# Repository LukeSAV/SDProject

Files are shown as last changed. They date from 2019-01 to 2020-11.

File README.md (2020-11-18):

# **SDProject**

Repo for senior design code

Link to project video: https://www.youtube.com/watch?v=O6JMgqfRybo&t=1s

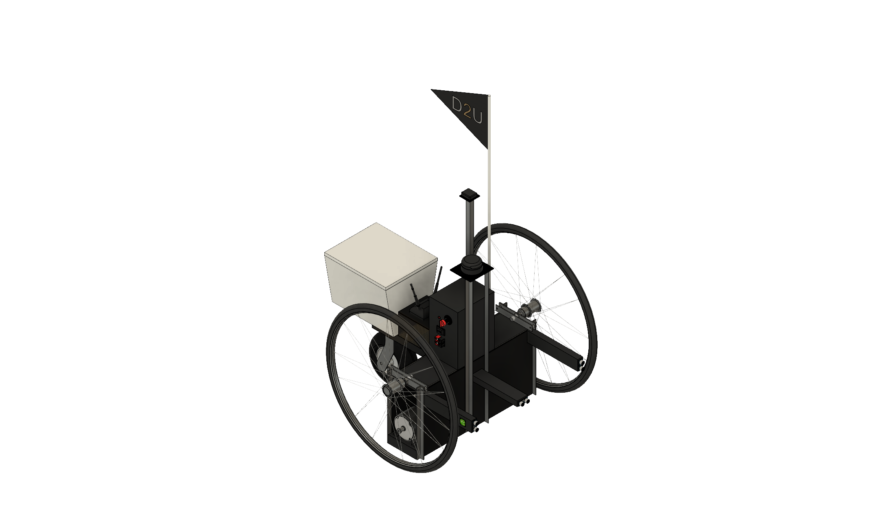
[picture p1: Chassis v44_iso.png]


## <u>Matlab</u>

Contains matlab test harness and associated files for the Extended Kalman Filter - This has since been converted to ekf_node in the ROS workspace.

## <u>SDMicro</u>

Contains all microcontroller related code for the project.

## <u>boards</u>

Contains files related to PCB design and schematics.

## <u>iOS</u>

This contains all project files related to XCode and iOS. 

##### /D2U

DeliveryInformation.swift - Singleton class used to hold relevant information to the delivery in progress.

DeliverySettingsController.swift - ViewController for the settings page. Formats and periodically updates the information on the page from FireBase.

MapMainController.swift - ViewController for the main map page. Handles map centering on desired user location and updates respective UI elements.

Waypoint.swift - Inherits MKPointAnnotation to apply color to dropped pins to distinguish between types.

## <u>ros_ws</u>

This is the ROS workspace for the project. Any packages/nodes made in ROS should be located here.

#### ROS Packages:

##### fb

This package contains the fb_node that handles interfacing to firebase. 

Nodes:

- fb_node: 
  - Publishes - /delivery_requested_status (Type: Bool)
  - Subscribes - /rtk_gpgga (Type: String)

##### rtk

This package contains the rtk_gps_node that runs code to support RTK corrections for the NS-HP-GL GPS/GNSS device. 

Nodes:

- rtk_gps_node
  - Publishes - /rtk_gpgga (Type: NavSatFix), /rtk_gpvtg (Type: HeadingSpeed)
  - Subscribes - None

##### rtk_controller

This package contains the rtk_controller node that performs path point generation to send to the microcontroller. A* algorithm, path point projection, and much more.

Nodes:

- rtk_controller_node
  - Publishes - /robot_cmd (Type: String), /next_waypoint (Type: NavSatFix), /goal_pt (Type: NavSatFix), /goal_math_pt (Type: NavSatFix)
  - Subscribes - /ekf/filtered (Type: NavSatFix), /ekf/imu/data (Type: Imu), /rtk_gpvtg (Type: String), /perception/map (Type: Image), /pitch (Type: Float32) 

##### joystick_drivers

This package contains the joy_node that interfaces the PS4 controller to ROS.

Nodes:

- joy_node: 
  - Publishes - /joy (Type: Joy)
  - Subscribes - None 

##### serial

This package contains the serial_node that handles all communication with the microcontroller.

Nodes:

- serial_node:
  - Publishes - /encoder (Type: String), /goal_string (Type: String)
  - Subscribes - /joy (Type: Joy), /delivery_requested_status (Type: Bool), /robot_cmd (Type: String)

##### perception

This package contains the lidar_node that handles creation of an obstacle map that the path planning algorithm may be run on.

Nodes:
- lidar_node:
  - Publishes - /perception/map (Type: Image)
  - Subscribes - /scan_img (Type: Image)
  
##### ekf

This package contains the ekf_node that runs the Extended Kalman Filter to fuse the robot sensor information.

Nodes:
- ekf_node:
  - Publishes - /ekf/filtered (Type: NavSatFix), /ekf/imu/data (Type: NavSatFix), /pitch (Type: Float32)
  - Subscribes - /imu/data (Type: Imu), /rtk_gpgga (Type: NavSatFix), /encoder (Type: String)

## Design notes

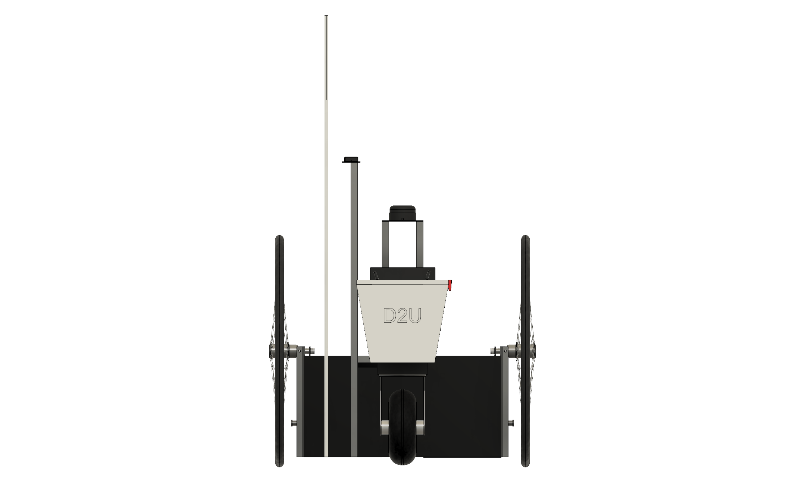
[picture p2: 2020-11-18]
Chassis v44_rear.png

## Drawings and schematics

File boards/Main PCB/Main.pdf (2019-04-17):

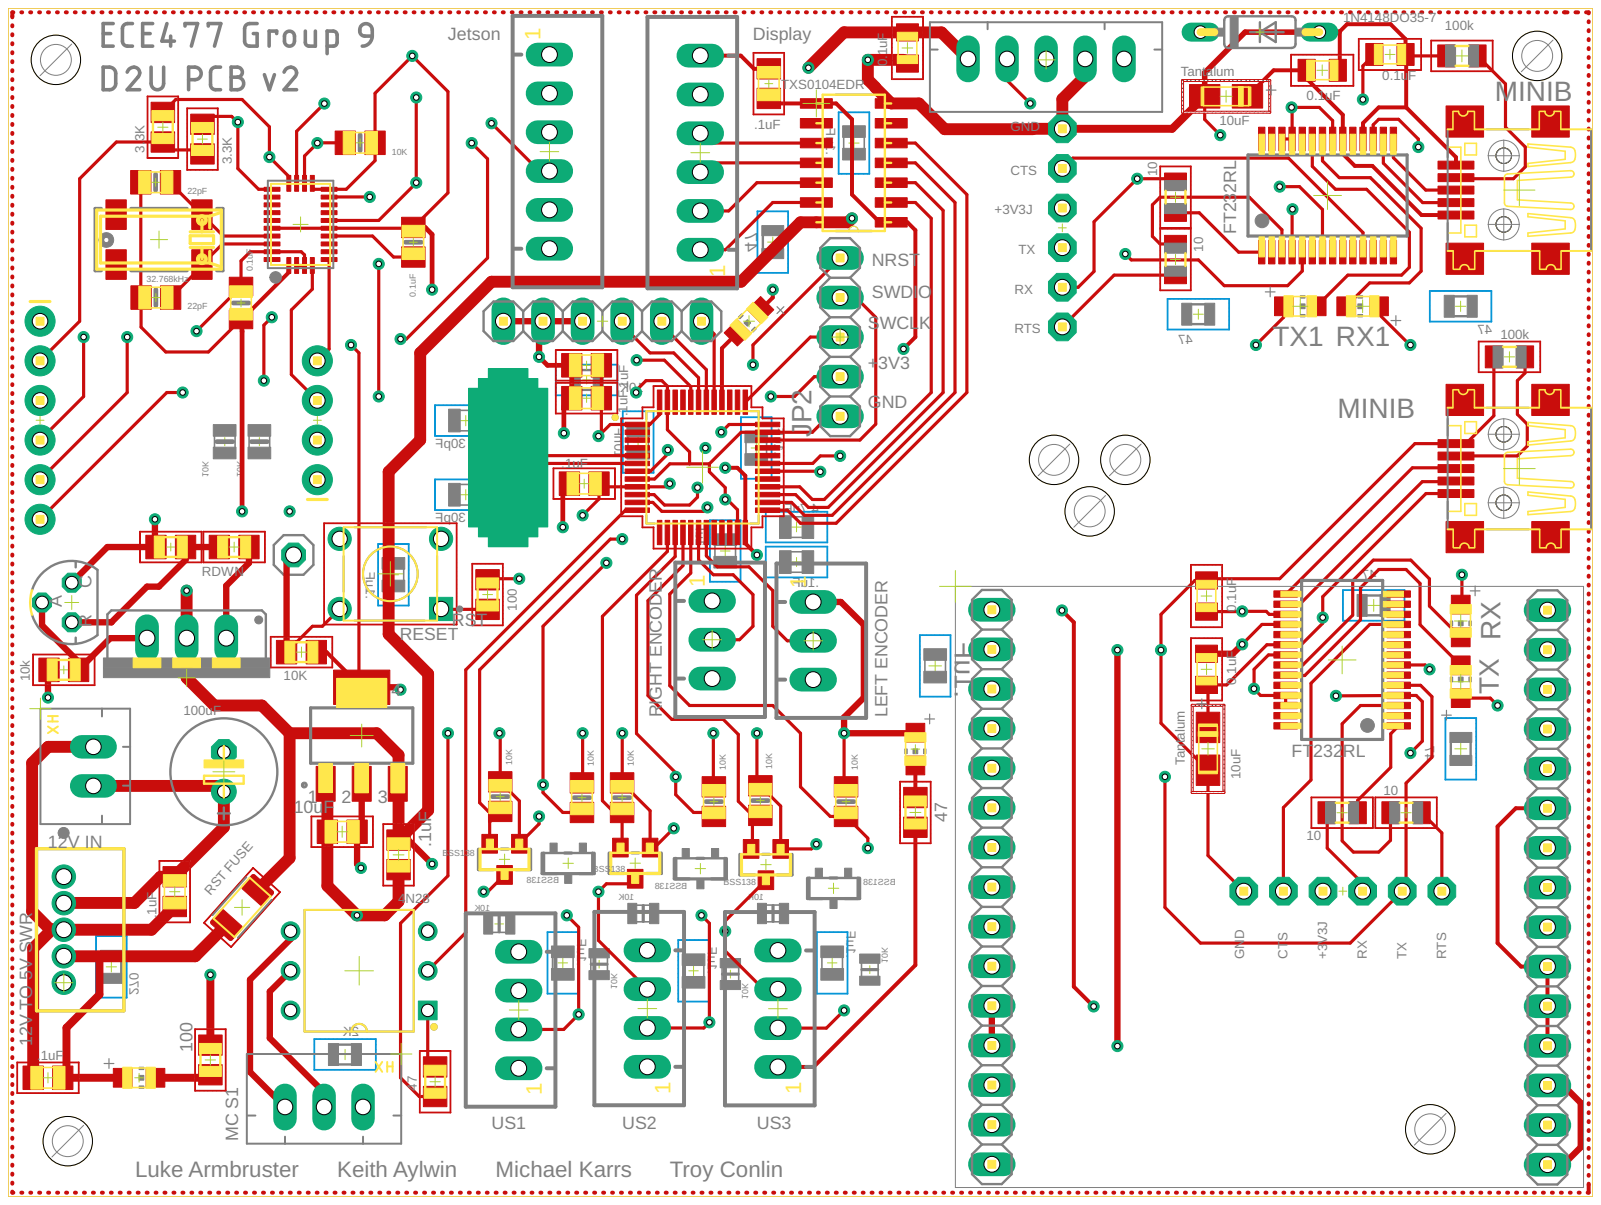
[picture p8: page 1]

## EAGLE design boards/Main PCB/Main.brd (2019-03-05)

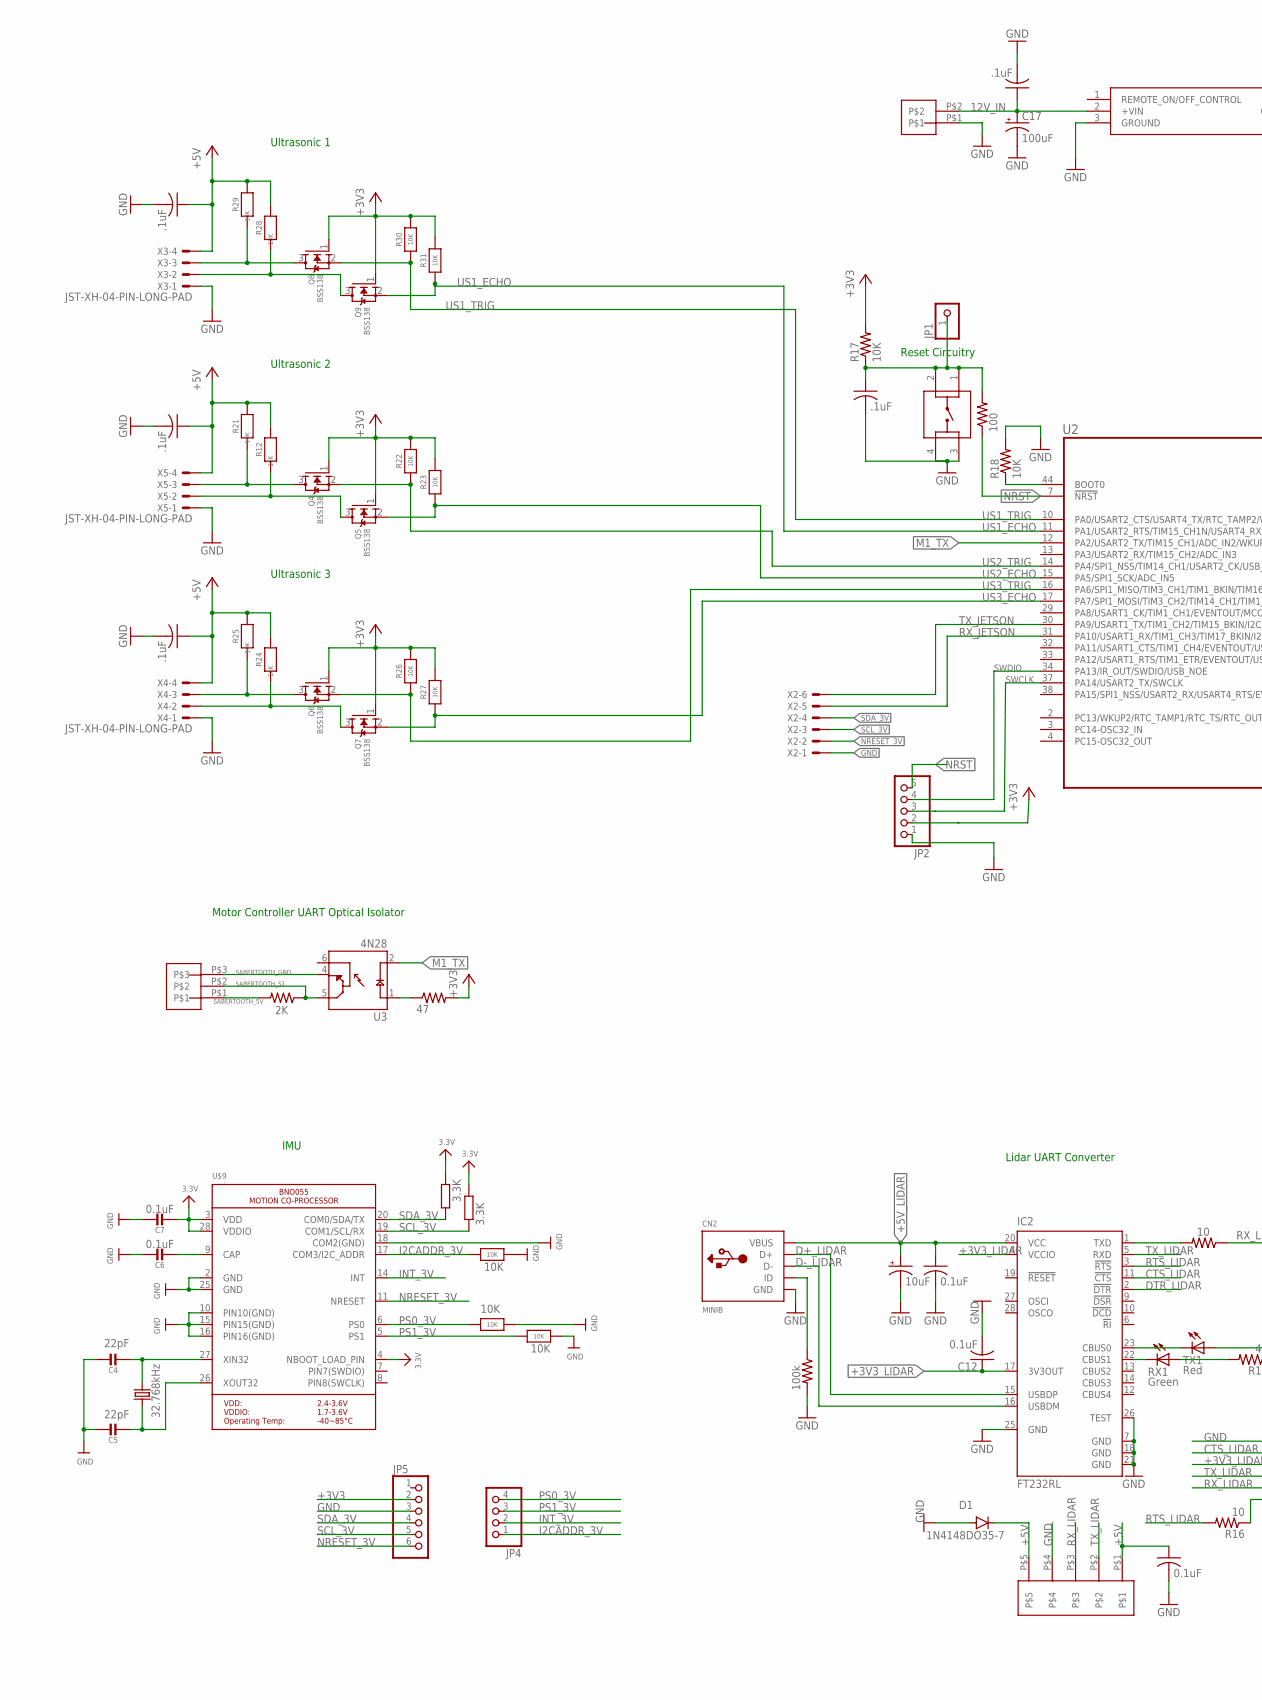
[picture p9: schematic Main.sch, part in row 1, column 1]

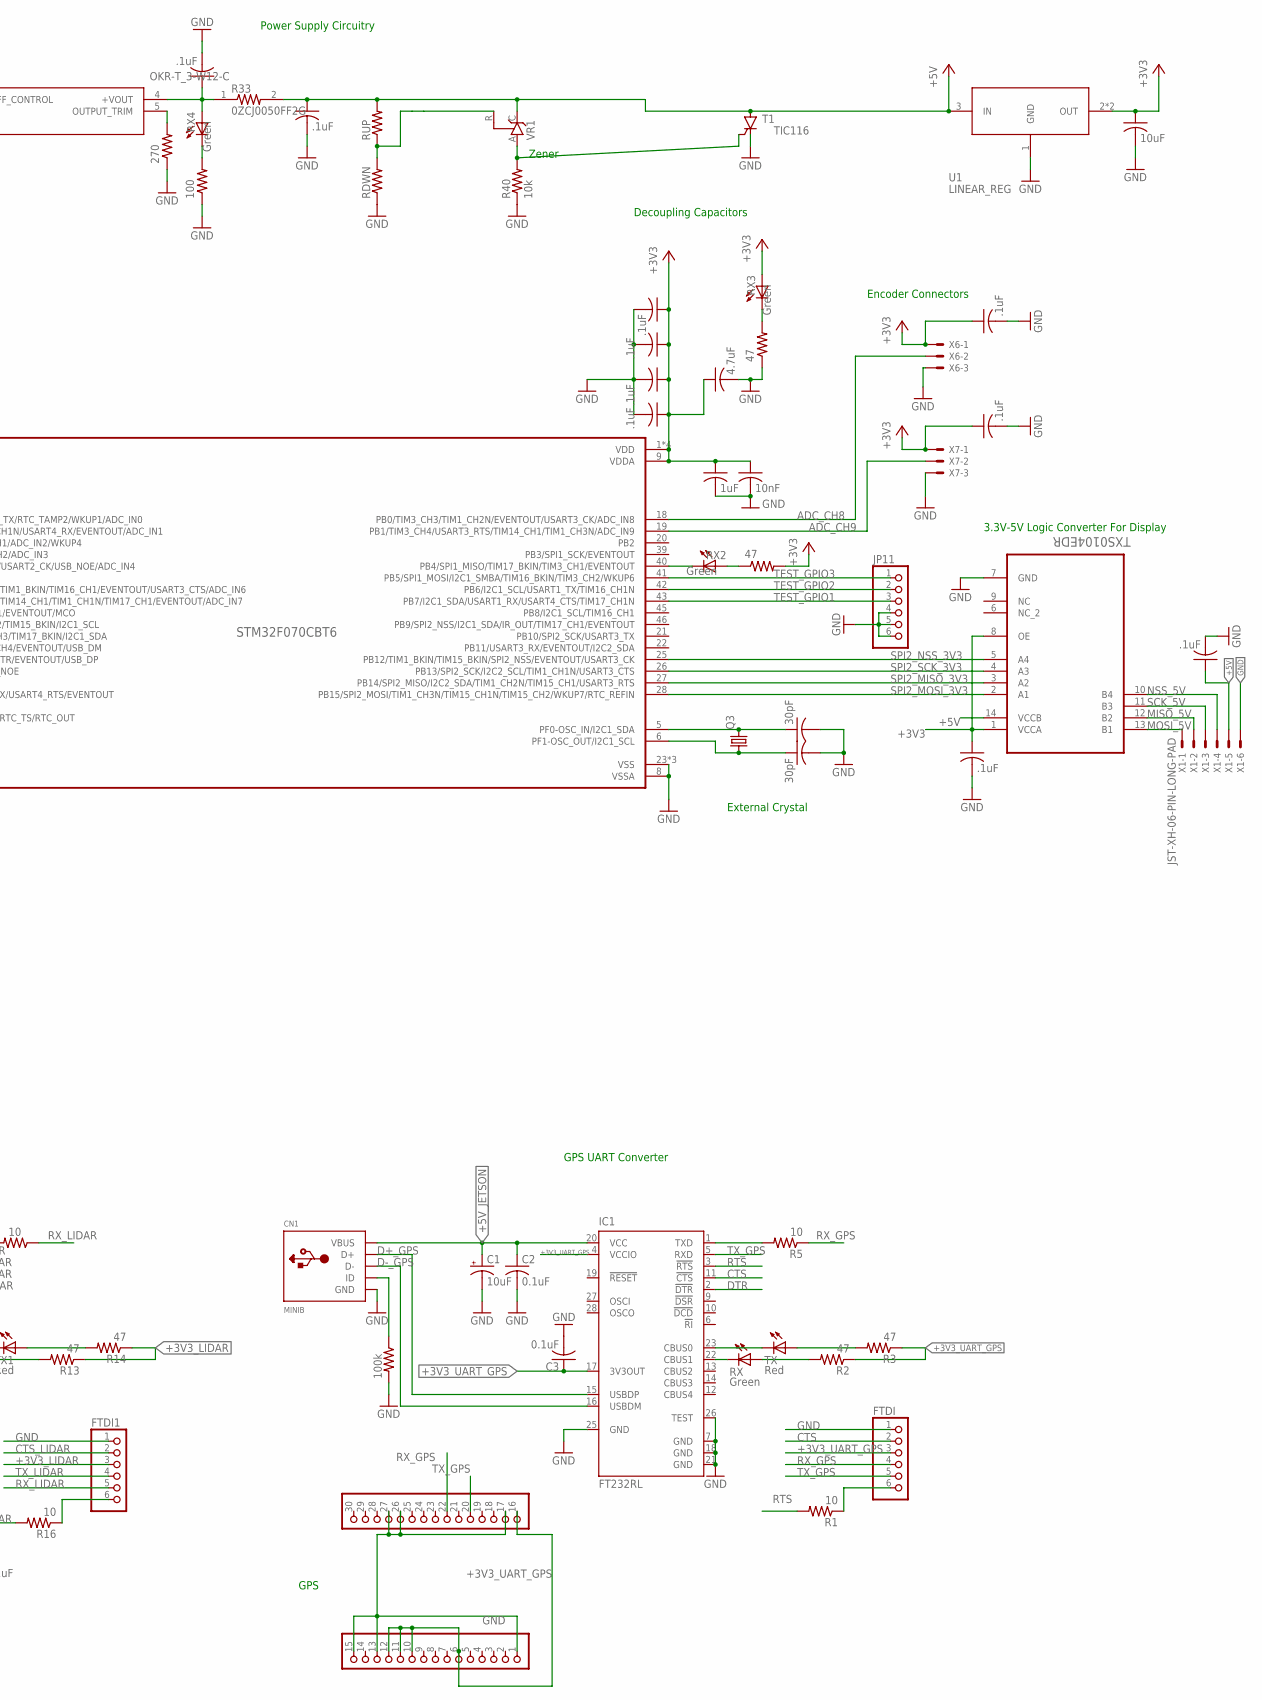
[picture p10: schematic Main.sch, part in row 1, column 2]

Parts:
C1, C10: 10uF; A/3216-18R
C2, C3, C11, C12, C30: 0.1uF; C0805K
C4, C5: 22pF; 0805-NO
C6: 0.1uF; 0805-NO
C7: 0.1uF; 0805_10MGAP
C8, C13, C18, C19, C22, C23, C24, C25, C26, C27, C28, C29, C31, C32, C33: .1uF; C0805
C9: 10uF; C0805
C14, C15: 30pF; C0805
C16: 4.7uF; C0805
C17: 100uF; E2,5-7
C20: 1uF; C0805
C21: 10nF; C0805
CN1, CN2: MINIB; USB-MINIB
D1: 1N4148DO35-7; DO35-7
FTDI, FTDI1: PINHD-1X6CB; 1X06-CLEANBIG
IC1, IC2: FT232RL; SSOP28
IC4: OKR-T_3-W12-C; MURATACASEC72
J1: 3_PIN_JST-XH
J2: 2_PIN_JST-XH
J3: 5_PIN_JST-XH
JP1: PINHD-1X1; 1X01
JP2: PINHD-1X5; 1X05
JP4: HEADER-1X476MIL; 1X04_ROUND_76
JP5: MICROBUILDER_HEADER-1X676MIL; MICROBUILDER_1X06_ROUND_76
JP11: PINHD-1X6; 1X06
Q3: CRYSTALHC49S; HC49/S
Q4, Q5, Q6, Q7, Q8, Q9: BSS138; SOT23-WIDE
R1, R5, R15, R16: 10; R0805
R2, R3, R10, R11, R13, R14, R19: 47; R0805
R4, R6, R7, R22, R23, R26, R27, R30, R31: 10K; 0805-NO
R8, R9: 3.3K; R0805
R12, R21, R24, R25, R28, R29: 10K; _0805MP
R17, R18: 10K; R0805
R20: 2K; R0805
R32, R37: 100; R0805
R33: 0ZCJ0050FF2G; RESC3216X125N
R34, R35: 100k; R0805
R36: 270; R0805
R40: 10k; R0805
RDWN: R-US_R0805; R0805
RESET: TACTILE_SWITCH; SW_1825910-6-4
RUP: R-US_R0805; R0805
RX, RX1, RX2, RX3, RX4: Green; CHIP-LED0805
T1: TIC116; TO220CS
TX, TX1: Red; CHIP-LED0805
U1: LINEAR_REG; SOT223
U2: STM32F070CBT6; QFP50P900X900X160-48N
U3: 4N28; DIP880W50P254L780H450Q6
U4: TXS0104EDR; SOIC127P600X175-14N
U$1: GPS
U$9: MICROBUILDER_BNO055
VR1: TL431CLP; TO92-CLP
X1, X2: JST-XH-06-PIN-LONG-PAD; JST-XH-06-PACKAGE-LONG-PAD
X3, X4, X5: JST-XH-04-PIN-LONG-PAD; JST-XH-04-PACKAGE-LONG-PAD
X6, X7: JST-XH-03-PIN-LONG-PAD; JST-XH-03-PACKAGE-LONG-PAD
Y1: 32.768kHz; CRYSTAL_8X3.8

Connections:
12V_IN: C17.+, C32.1, IC4.2 (+VIN), J2.P$2
+3V3: C7.2, C9.1, C16.1, C20.1, C21.1, C22.1, C23.1, C24.1, C25.1, C28.1, C29.1, C33.1, JP2.2, JP5.2, Q4.1 (G), Q5.1 (G), Q6.1 (G), Q7.1 (G), Q8.1 (G), Q9.1 (G), R8.2, R9.2, R10.2, R17.2, R19.2, R22.2, R23.2, R26.2, R27.2, R30.2, R31.2, RX3.A, U1.2 (OUT), U1.4 (OUT), U2.1 (VDD), U2.9 (VDDA), U2.24 (VDD), U2.36 (VDD), U2.48 (VDD), U4.1 (VCCA), U4.8 (OE), U$9.3 (VDD), U$9.4 (NBOOT_LOAD_PIN), U$9.28 (VDDIO), X6.1, X7.1
+3V3_LIDAR: C12.1, FTDI1.3, IC2.4 (VCCIO), IC2.17 (3V3OUT), R13.1, R14.1
+3V3_UART_GPS: C3.1, FTDI.3, IC1.4 (VCCIO), IC1.17 (3V3OUT), R2.1, R3.1, U$1.6, U$1.10, U$1.11, U$1.12, U$1.16 (1)
+5V: C8.1, C18.1, C19.1, C26.1, C27.1, C30.1, D1.C, J3.P$1, J3.P$5, R12.2, R21.2, R24.2, R25.2, R28.2, R29.2, R33.2, RUP.2, T1.A, U1.3 (IN), U4.14 (VCCB), VR1.C, X1.5, X3.4, X4.4, X5.4
+5V_JETSON: C1.+, C2.1, CN1.VBUS, IC1.20 (VCC)
+5V_LIDAR: C10.+, C11.1, CN2.VBUS, IC2.20 (VCC)
ADC_CH8: U2.18 (PB0/TIM3_CH3/TIM1_CH2N/EVENTOUT/USART3_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), X6.2
ADC_CH9: U2.19 (PB1/TIM3_CH4/USART3_RTS/TIM14_CH1/TIM1_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), X7.2
BOOT0: R18.1, U2.44 (BOOT0)
CAP: C6.2, U$9.9 (CAP)
CTS: FTDI.2, IC1.11 (!CTS)
CTS_LIDAR: FTDI1.2, IC2.11 (!CTS)
D+_GPS: CN1.D+, IC1.15 (USBDP)
D+_LIDAR: CN2.D+, IC2.15 (USBDP)
D-_GPS: CN1.D-, IC1.16 (USBDM)
D-_LIDAR: CN2.D-, IC2.16 (USBDM)
DTR: IC1.2 (!DTR)
DTR_LIDAR: IC2.2 (!DTR)
GND: C1.-, C2.2, C3.2, C4.1, C5.1, C6.1, C7.1, C8.2, C9.2, C10.-, C11.2, C12.2, C13.2, C14.2, C15.2, C16.2, C17.-, C18.2, C19.2, C20.2, C21.2, C22.2, C23.2, C24.2, C25.2, C26.2, C27.2, C28.2, C29.2, C30.2, C31.2, C32.2, C33.2, CN1.GND, CN2.GND, D1.A, FTDI.1, FTDI1.1, IC1.7 (GND), IC1.18 (GND), IC1.21 (GND), IC1.25 (GND), IC1.26 (TEST), IC2.7 (GND), IC2.18 (GND), IC2.21 (GND), IC2.25 (GND), IC2.26 (TEST), IC4.3 (GROUND), J2.P$1, J3.P$4, JP2.1, JP5.3, JP11.4, JP11.5, JP11.6, R4.2, R6.2, R7.2, R11.1, R18.2, R32.1, R34.2, R35.2, R36.1, R40.1, RDWN.1, RESET.3, RESET.4, T1.C, U1.1 (GND), U2.8 (VSSA), U2.23 (VSS), U2.35 (VSS), U2.47 (VSS), U4.7 (GND), U$1.1, U$1.13, U$1.15, U$1.17 (2), U$1.26 (11), U$1.27 (12), U$9.2 (GND), U$9.10 (PIN10(GND)), U$9.15 (PIN15(GND)), U$9.16 (PIN16(GND)), U$9.18 (COM2(GND)), U$9.25 (GND), X1.6, X2.1, X3.1, X4.1, X5.1, X6.3, X7.3
I2CADDR_3V: JP4.1, R7.1, U$9.17 (COM3/I2C_ADDR)
INT_3V: JP4.2, U$9.14 (INT)
LED: RX2.C, U2.40 (PB4/SPI1_MISO/TIM17_BKIN/TIM3_CH1/EVENT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)
M1_TX: U2.12 (PA2/USART2_TX/TIM15_CH1/ADC_IN2/WKUP4), U3.2 (C_D)
MISO_5V: U4.12 (B2), X1.2
MOSI_5V: U4.13 (B1), X1.1
unnamed: C4.2, U$9.27 (XIN32), Y1.P$4 (2)
unnamed: FTDI.6, R1.1
unnamed: R10.1, RX2.A
unnamed: R11.2, RX3.C
unnamed: IC1.1 (TXD), R5.2
unnamed: IC1.23 (CBUS0), TX.C
unnamed: IC1.22 (CBUS1), RX.C
unnamed: R2.2, RX.A
unnamed: R3.2, TX.A
unnamed: C5.2, U$9.26 (XOUT32), Y1.P$1 (1)
unnamed: CN2.ID, R34.1
unnamed: R32.2, RX4.C
unnamed: CN1.ID, R35.1
unnamed: IC2.23 (CBUS0), TX1.C
unnamed: IC2.22 (CBUS1), RX1.C
unnamed: R13.2, RX1.A
unnamed: R14.2, TX1.A
unnamed: IC2.1 (TXD), R15.2
unnamed: FTDI1.6, R16.1
unnamed: IC4.5 (OUTPUT_TRIM), R36.2
unnamed: C31.1, IC4.4 (+VOUT), R33.1, RX4.A
unnamed: Q4.3 (D), R21.1, X5.3
unnamed: Q5.3 (D), R12.1, X5.2
unnamed: R40.2, T1.G, VR1.A
unnamed: RDWN.2, RUP.1, VR1.R
unnamed: Q6.3 (D), R25.1, X4.3
unnamed: Q7.3 (D), R24.1, X4.2
unnamed: R19.1, U3.1 (A_D)
unnamed: C14.1, Q3.2, U2.5 (PF0-OSC_IN/I2C1_SDA)
unnamed: C15.1, Q3.1, U2.6 (PF1-OSC_OUT/I2C1_SCL)
unnamed: Q8.3 (D), R29.1, X3.3
unnamed: Q9.3 (D), R28.1, X3.2
NRESET_3V: JP5.6, U$9.11 (NRESET), X2.2
NRST: JP2.5, R37.1, U2.7 (!NRST)
NSS_5V: U4.10 (B4), X1.4
PS0_3V: JP4.4, R4.1, U$9.6 (PS0)
PS1_3V: JP4.3, R6.1, U$9.5 (PS1)
RESET: C13.1, JP1.1, R17.1, R37.2, RESET.1, RESET.2
RTS: IC1.3 (!RTS), R1.2
RTS_LIDAR: IC2.3 (!RTS), R16.2
RX_GPS: FTDI.4, R5.1, U$1.22 (7)
RX_JETSON: U2.31 (PA10/USART1_RX/TIM1_CH3/TIM17_BKIN/I2C1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), X2.5
RX_LIDAR: FTDI1.5, J3.P$3, R15.1
SABERTOOTH_5V: J1.P$1, R20.2
SABERTOOTH_GND: J1.P$3, U3.4 (E_T)
SABERTOOTH_S1: J1.P$2, R20.1, U3.5 (C_T)
SCK_5V: U4.11 (B3), X1.3
SCL_3V: JP5.5, R9.1, U$9.19 (COM1/SCL/RX), X2.3
SDA_3V: JP5.4, R8.1, U$9.20 (COM0/SDA/TX), X2.4
SPI2_MISO_3V3: U2.27 (PB14/SPI2_MISO/I2C2_SDA/TIM1_CH2N/TIM15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), U4.3 (A2)
SPI2_MOSI_3V3: U2.28 (PB15/SPI2_MOSI/TIM1_CH3N/TIM15_CH1N/TIM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), U4.2 (A1)
SPI2_NSS_3V3: U2.25 (PB12/TIM1_BKIN/TIM15_BKIN/SPI2_NSS/EVEN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), U4.5 (A4)
SPI2_SCK_3V3: U2.26 (PB13/SPI2_SCK/I2C2_SCL/TIM1_CH1N/USART3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), U4.4 (A3)
SWCLK: JP2.3, U2.37 (PA14/USART2_TX/SWCLK)
SWDIO: JP2.4, U2.34 (PA13/IR_OUT/SWDIO/USB_NOE)
TEST_GPIO1: JP11.3, U2.43 (PB7/I2C1_SDA/USART1_RX/USART4_CTS/TIM17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)
TEST_GPIO2: JP11.2, U2.42 (PB6/I2C1_SCL/USART1_TX/TIM16_CH1N)
TEST_GPIO3: JP11.1, U2.41 (PB5/SPI1_MOSI/I2C1_SMBA/TIM16_BKIN/TIM3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)
TX_GPS: FTDI.5, IC1.5 (RXD), U$1.20 (5)
TX_JETSON: U2.30 (PA9/USART1_TX/TIM1_CH2/TIM15_BKIN/I2C1_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), X2.6
TX_LIDAR: FTDI1.4, IC2.5 (RXD), J3.P$2
US1_ECHO: Q9.2 (S), R31.1, U2.11 (PA1/USART2_RTS/TIM15_CH1N/USART4_RX/EVE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)
US1_TRIG: Q8.2 (S), R30.1, U2.10 (PA0/USART2_CTS/USART4_TX/RTC_TAMP2/WKUP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)
US2_ECHO: Q5.2 (S), R23.1, U2.15 (PA5/SPI1_SCK/ADC_IN5)
US2_TRIG: Q4.2 (S), R22.1, U2.14 (PA4/SPI1_NSS/TIM14_CH1/USART2_CK/USB_NO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)
US3_ECHO: Q7.2 (S), R27.1, U2.17 (PA7/SPI1_MOSI/TIM3_CH2/TIM14_CH1/TIM1_C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)
US3_TRIG: Q6.2 (S), R26.1, U2.16 (PA6/SPI1_MISO/TIM3_CH1/TIM1_BKIN/TIM16_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)

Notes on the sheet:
Power Supply Circuitry
GPS
GPS UART Converter
Ultrasonic 1
Ultrasonic 2
Ultrasonic 3
Motor Controller UART Optical Isolator
IMU
Lidar UART Converter
Reset Circuitry
External Crystal
3.3V-5V Logic Converter For Display
Encoder Connectors
Decoupling Capacitors
10K
Zener

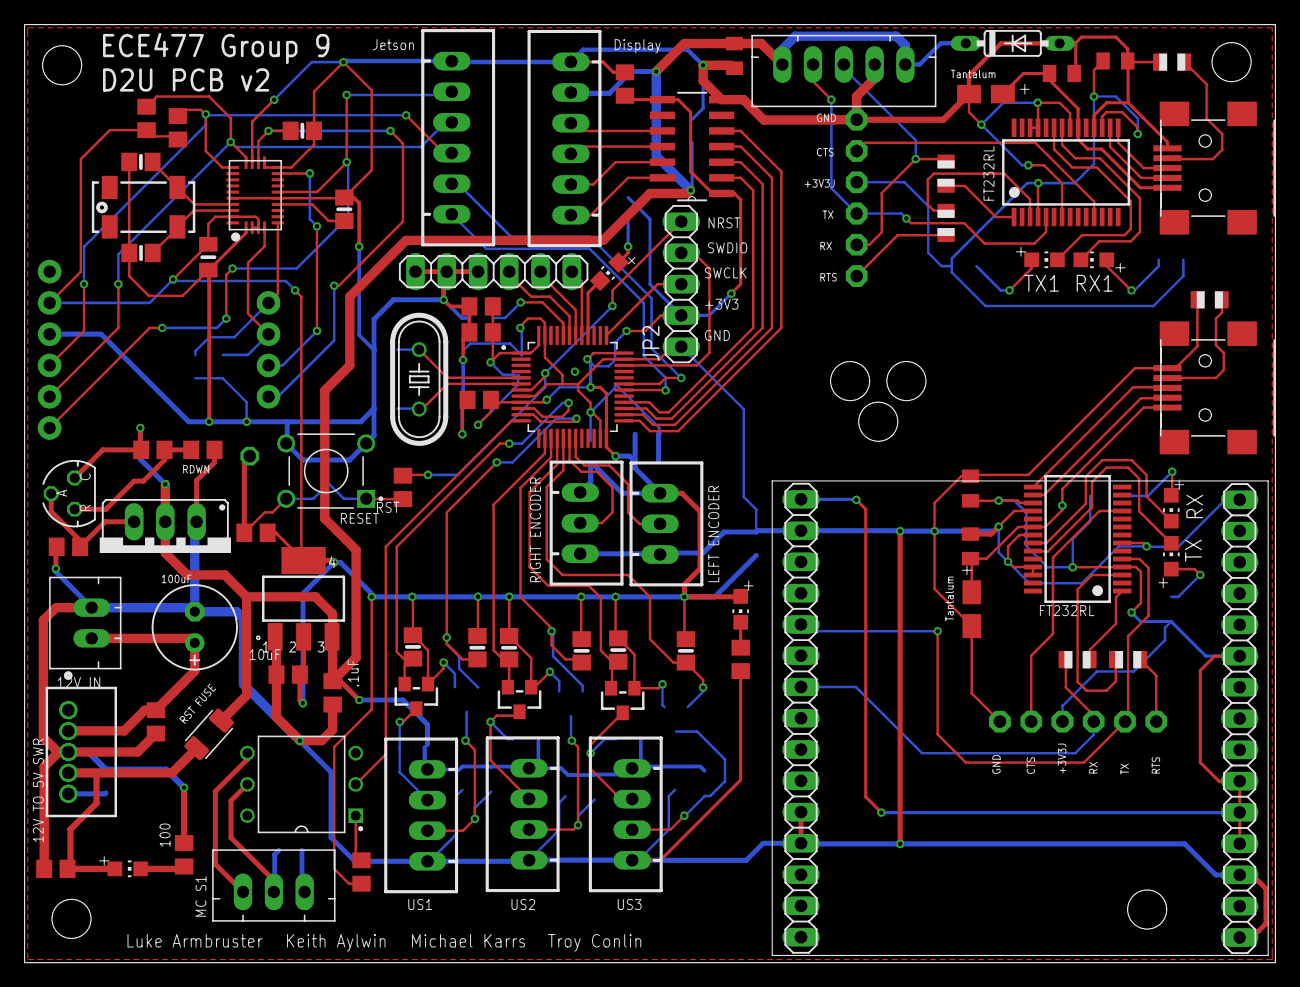
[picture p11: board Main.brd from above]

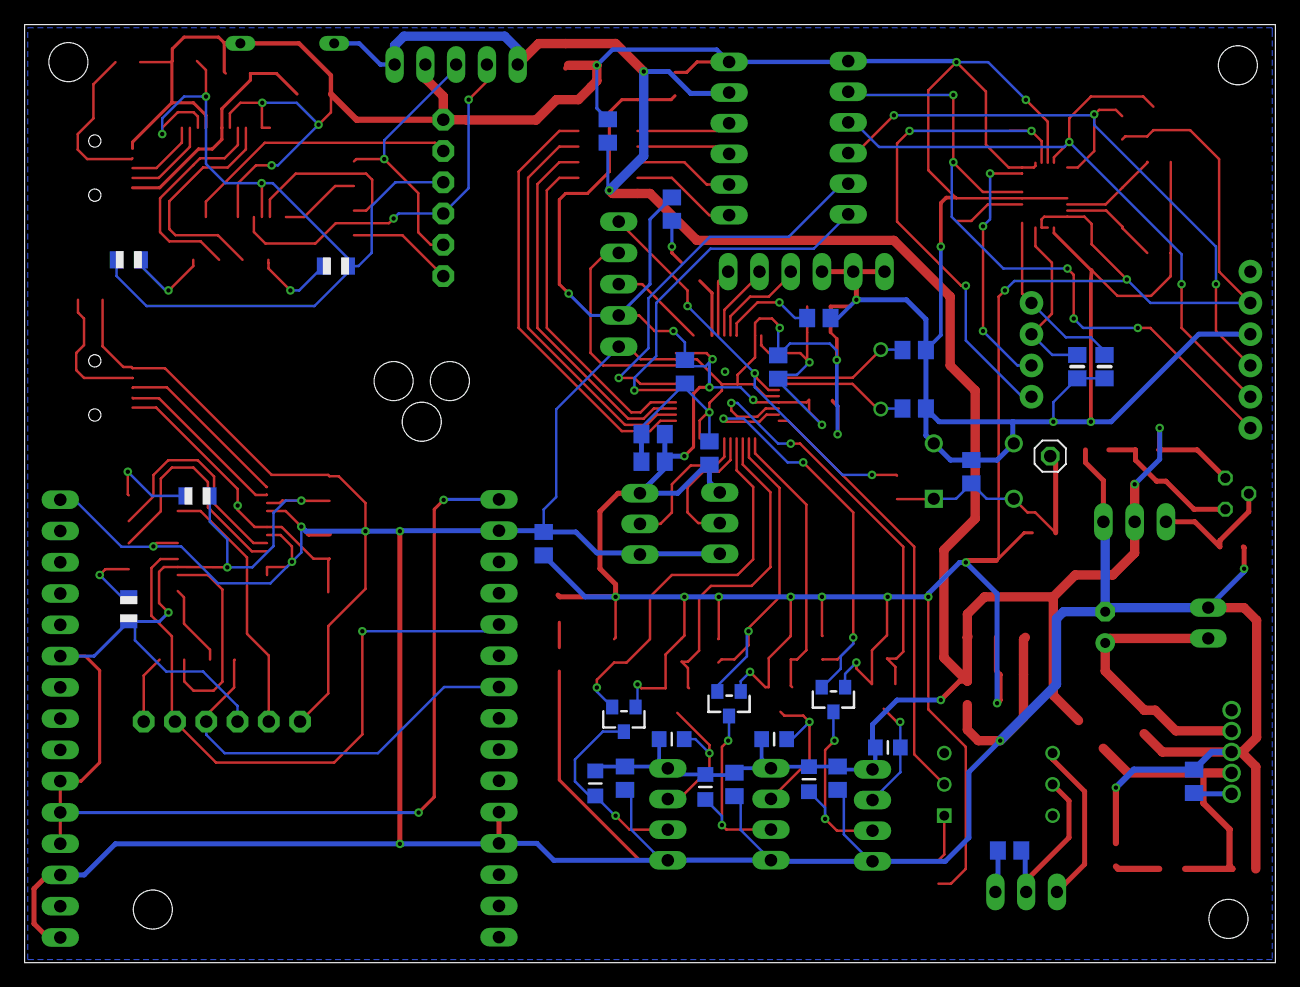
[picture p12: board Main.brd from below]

Board: 2 copper layers, 101.6 x 76.2 mm, 120 parts (33 on the bottom side), 91 nets.

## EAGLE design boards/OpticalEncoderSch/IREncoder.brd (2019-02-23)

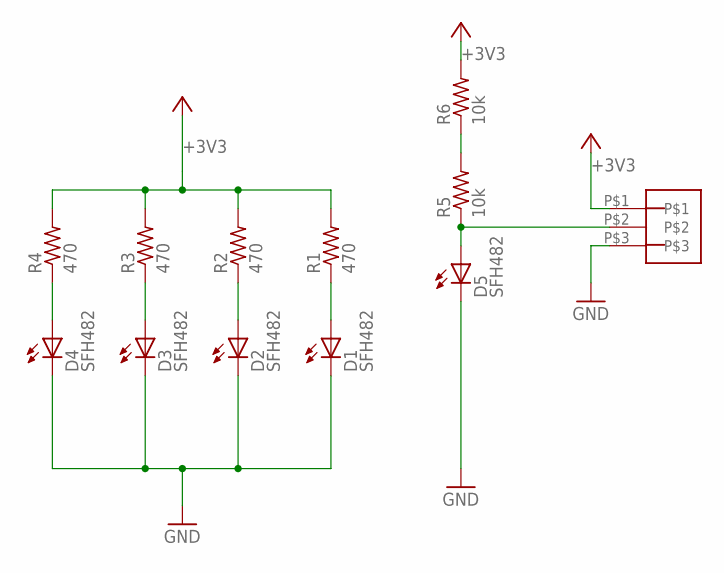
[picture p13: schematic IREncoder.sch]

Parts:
D1, D2, D3, D4, D5: SFH482
J1: 3_PIN_JST-XH
R1, R2, R3, R4: 470; R0805
R5, R6: 10k; R0805

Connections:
+3V3: J1.P$1, R1.2, R2.2, R3.2, R4.2, R6.2
GND: D1.K (C), D2.K (C), D3.K (C), D4.K (C), D5.K (C), J1.P$3
unnamed: D4.A, R4.1
unnamed: D3.A, R3.1
unnamed: D2.A, R2.1
unnamed: D1.A, R1.1
unnamed: D5.A, J1.P$2, R5.1
unnamed: R5.2, R6.1

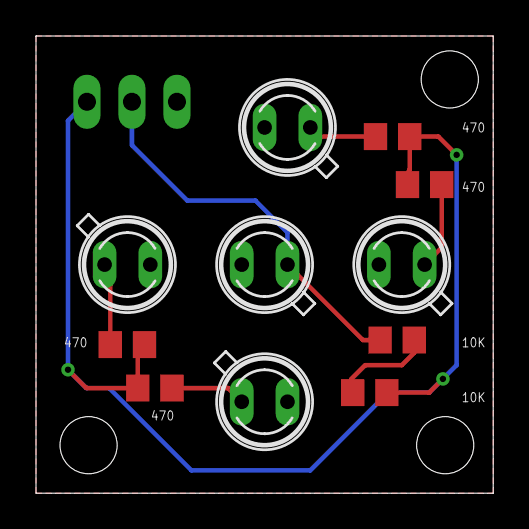
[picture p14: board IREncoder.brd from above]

Board: 2 copper layers, 25.4 x 25.4 mm, 12 parts (1 on the bottom side), 8 nets.

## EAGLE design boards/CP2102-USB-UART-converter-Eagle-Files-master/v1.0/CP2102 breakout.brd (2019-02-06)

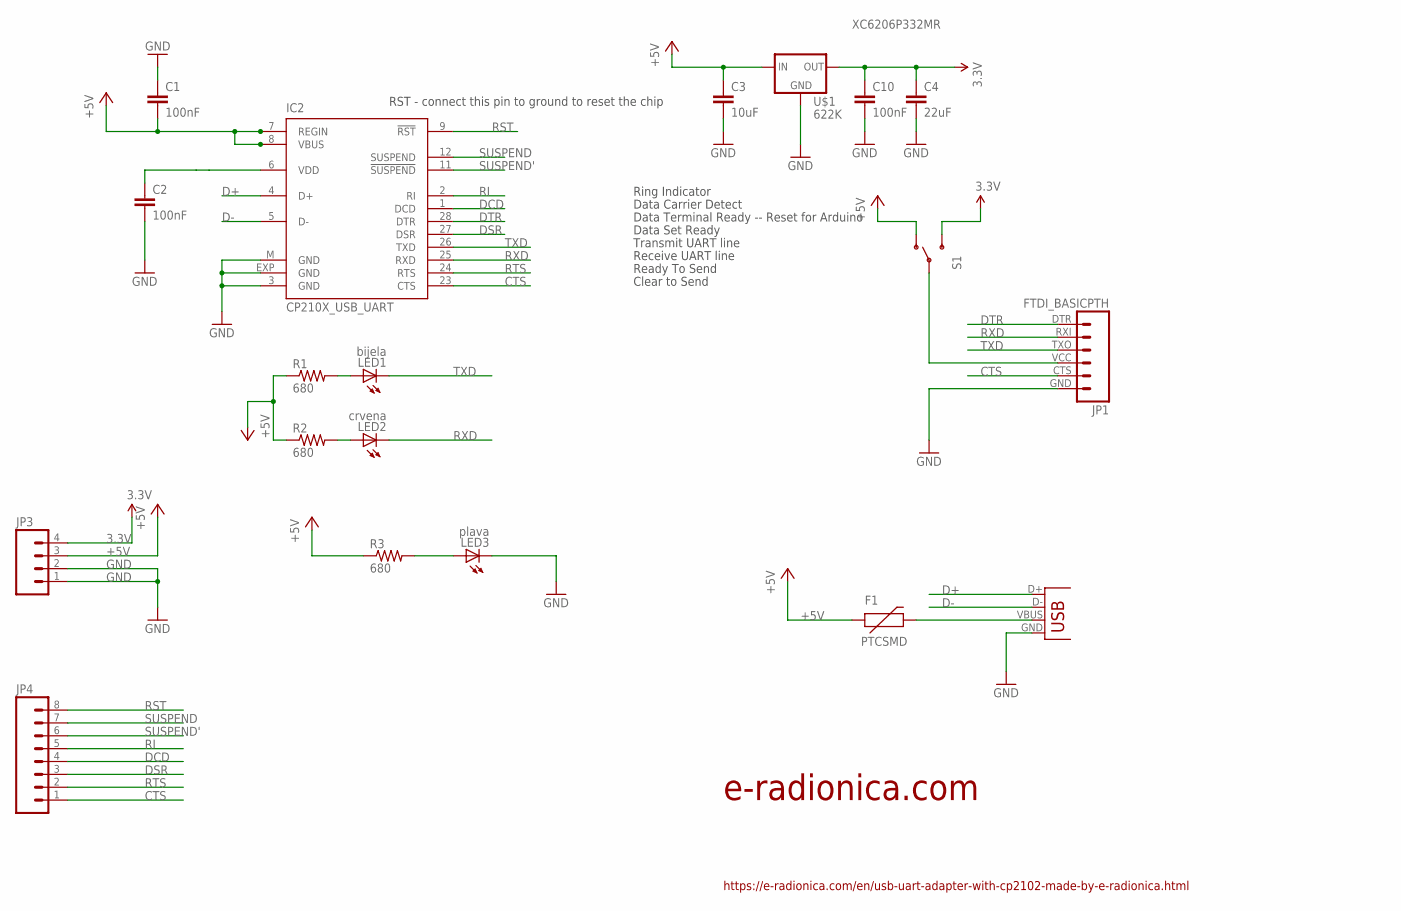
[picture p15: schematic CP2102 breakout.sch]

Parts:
C1, C2, C10: 100nF; 0603-CAP
C3: 10uF; C3216
C4: 22uF; C3216
F1: PTCSMD; PTC-1206
IC2: CP210X_USB_UART; MLP28
JP1: FTDI_BASICPTH; FTDI_BASIC
JP3: M04PTH; 1X04
JP4: M081X08; 1X08
LED1: bijela; CHIP-LED0805
LED2: crvena; CHIP-LED0805
LED3: plava; CHIP-LED0805
R1, R2, R3: 680; 0603-RES
S1: SWITCH-SPST-SMD-A
U$1: 622K; 662K
X1: USB-MICROB

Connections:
3.3V: C4.1, C10.1, JP3.4, S1.3 (S), U$1.OUT
+5V: C1.2, C3.1, F1.1, IC2.7 (REGIN), IC2.8 (VBUS), JP3.3, R1.1, R2.1, R3.1, S1.1 (O), U$1.IN
CTS: IC2.23 (CTS), JP1.CTS (5), JP4.1
D+: IC2.4 (D+), X1.D+
D-: IC2.5 (D-), X1.D-
DCD: IC2.1 (DCD), JP4.4
DSR: IC2.27 (DSR), JP4.3
DTR: IC2.28 (DTR), JP1.DTR (1)
GND: C1.1, C2.2, C3.2, C4.2, C10.2, IC2.3 (GND), IC2.EXP (GND), IC2.M (GND), JP1.GND (6), JP3.1, JP3.2, LED3.C, U$1.GND, X1.GND
unnamed: LED1.A, R1.2
unnamed: LED2.A, R2.2
unnamed: LED3.A, R3.2
unnamed: C2.1, IC2.6 (VDD)
RI: IC2.2 (RI), JP4.5
RST: IC2.9 (!RST), JP4.8
RTS: IC2.24 (RTS), JP4.2
RXD: IC2.25 (RXD), JP1.RXI (2), LED2.C
SUSPEND: IC2.12 (SUSPEND), JP4.7
SUSPEND': IC2.11 (!SUSPEND), JP4.6
TXD: IC2.26 (TXD), JP1.TXO (3), LED1.C
VBUS: F1.2, X1.VBUS
VCC: JP1.VCC (4), S1.2

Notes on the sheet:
RST - connect this pin to ground to reset the chip
Clear to Send
Data Terminal Ready -- Reset for Arduino
Data Set Ready
Transmit UART line
Receive UART line
Data Carrier Detect
Ring Indicator
Ready To Send
XC6206P332MR
https://e-radionica.com/en/usb-uart-adapter-with-cp2102-made-by-e-radionica.html
e-radionica.com

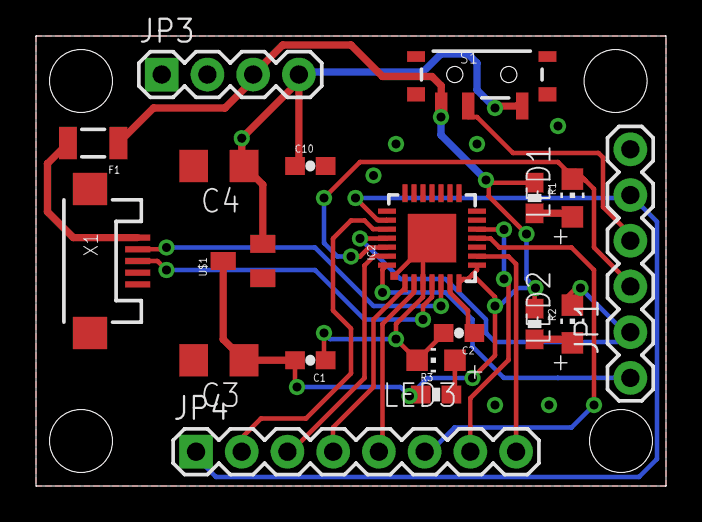
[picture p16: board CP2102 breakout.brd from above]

Board: 2 copper layers, 35.0 x 25.0 mm, 23 parts (0 on the bottom side), 22 nets.

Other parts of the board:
U$2: OSH3MM
U$3: NOVI_LOGO-4MM
U$4: LUDI_LOGO_BACK
U$5: E-RADIONICA.COM_MADE_IN_BACK!

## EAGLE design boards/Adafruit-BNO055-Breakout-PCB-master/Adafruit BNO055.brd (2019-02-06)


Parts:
C1, C2: 22pF; 0805-NO
C3: 0.1uF; 0805-NO
C4: 0.1uF; 0805_10MGAP
C5: 10uF; 0805-NO
C6: 10uF; 0805_10MGAP
D1: 1n4148; SOD-323
FID1, FID2: FIDUCIAL""; FIDUCIAL_1MM
JP1: HEADER-1X676MIL; 1X06_ROUND_76
JP2: HEADER-1X476MIL; 1X04_ROUND_76
Q1, Q2: BSS138; SOT23-WIDE
R3, R4, R5, R6, R7, R10: 10K; 0805-NO
R8, R9: 10K; _0805MP
U1: MIC5225-3.3; SOT23-5
U$2: BNO055
U$29, U$30, U$31, U$32: MOUNTINGHOLE2.5_THICK; MOUNTINGHOLE_2.5_PLATED_THICK
Y1: 32.768kHz; CRYSTAL_8X3.8

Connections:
3.3V: C4.2, C6.1, JP1.2, Q1.1 (G), Q2.1 (G), R6.2, R7.2, R10.2, U1.5 (OUT), U$2.3 (VDD), U$2.4 (NBOOT_LOAD_PIN), U$2.28 (VDDIO)
5.0V: C5.1, JP1.1, R8.2, R9.2, U1.1 (IN), U1.3 (EN)
GND: C1.1, C2.1, C3.1, C4.1, C5.2, C6.2, JP1.3, R3.2, R4.2, R5.2, U1.2 (GND), U$2.2 (GND), U$2.10 (PIN10(GND)), U$2.15 (PIN15(GND)), U$2.16 (PIN16(GND)), U$2.18 (COM2(GND)), U$2.25 (GND)
I2CADDR_3V: JP2.4, R5.1, U$2.17 (COM3/I2C_ADDR)
INT_3V: JP2.3, U$2.14 (INT)
unnamed: C1.2, U$2.27 (XIN32), Y1.P$4 (2)
unnamed: C2.2, U$2.26 (XOUT32), Y1.P$1 (1)
unnamed: C3.2, U$2.9 (CAP)
NRESET_3V: D1.A, R10.1, U$2.11 (NRESET)
PS0_3V: JP2.1, R3.1, U$2.6 (PS0)
PS1_3V: JP2.2, R4.1, U$2.5 (PS1)
RST_5V: D1.C, JP1.6
SCL_3V: Q2.2 (S), R7.1, U$2.19 (COM1/SCL/RX)
SCL_5V: JP1.5, Q2.3 (D), R9.1
SDA_3V: Q1.2 (S), R6.1, U$2.20 (COM0/SDA/TX)
SDA_5V: JP1.4, Q1.3 (D), R8.1



Board: 2 copper layers, 26.7 x 20.3 mm, 31 parts (2 on the bottom side), 16 nets.

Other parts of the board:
U$3: PCBFEAT-REV-040
U$28: ADAFRUIT_TEXT_20MM
U$33: ADAFRUIT_2.5MM

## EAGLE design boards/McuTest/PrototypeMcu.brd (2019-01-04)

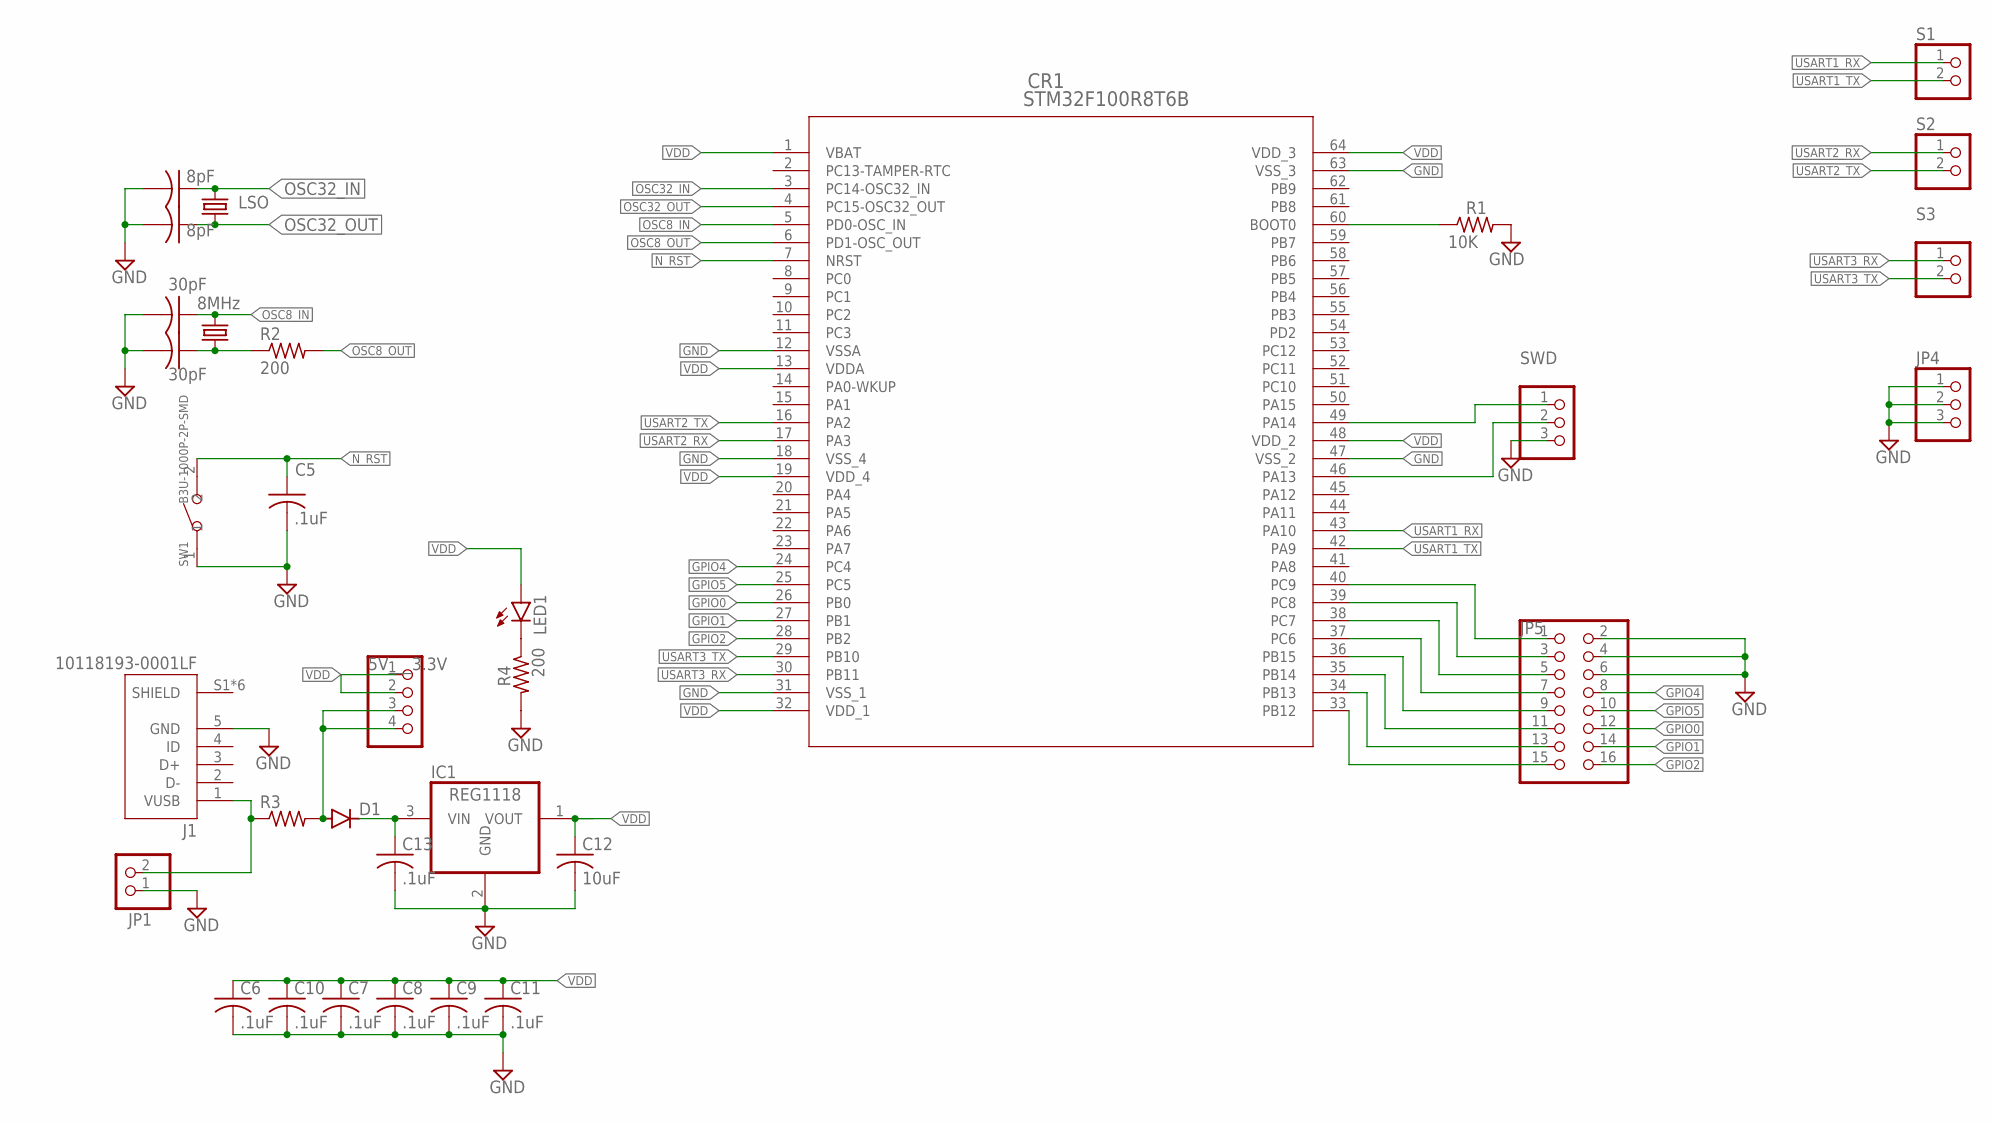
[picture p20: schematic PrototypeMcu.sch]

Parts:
5V___3.3V: PINHD-1X4; 1X04
C1, C2: 8pF; C0402
C3, C4: 30pF; C0402
C5, C6, C7, C8, C9, C10, C11, C13: .1uF; C0402
C12: 10uF; C0402
CR1: STM32F100R8T6B; LQFP-64
D1: DIODE-SOD57-10; SOD57-10
IC1: REG1118; SOT223
J1: 10118193-0001LF; FCI_10118193-0001LF
JP1: PINHD-1X2; 1X02
JP4: PINHD-1X3; 1X03
JP5: PINHD-2X8; 2X08
LED1: LEDCHIPLED_0603; CHIPLED_0603
LSO: CRYSTALTC26V; TC26V
Q1: 8MHz; HC49/S
R1: 10K; R0402
R2, R4: 200; R0402
R3: R-US_M1206; M1206
S1, S2, S3: PINHD-1X2; 1X02
SW1: B3U-1000P-2P-SMD; SW2-2.6-3.0X2.5X1.2+0.4MM
SWD: PINHD-1X3; 1X03

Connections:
GND: C1.2, C2.2, C3.2, C4.2, C5.2, C6.2, C7.2, C8.2, C9.2, C10.2, C11.2, C12.2, C13.2, CR1.12 (VSSA), CR1.18 (VSS_4), CR1.31 (VSS_1), CR1.47 (VSS_2), CR1.63 (VSS_3), IC1.2 (GND), J1.5 (GND), JP1.1, JP4.1, JP4.2, JP4.3, JP5.2, JP5.4, JP5.6, R1.2, R4.2, SW1.1, SWD.3
GPIO0: CR1.26 (PB0), JP5.12
GPIO1: CR1.27 (PB1), JP5.14
GPIO2: CR1.28 (PB2), JP5.16
GPIO4: CR1.24 (PC4), JP5.8
GPIO5: CR1.25 (PC5), JP5.10
unnamed: CR1.60 (BOOT0), R1.1
unnamed: C13.1, D1.C, IC1.3 (VIN)
unnamed: CR1.40 (PC9), JP5.1
unnamed: 5V___3.3V.3, 5V___3.3V.4, D1.A, R3.2
unnamed: C4.1, Q1.2, R2.1
unnamed: CR1.46 (PA13), SWD.2
unnamed: CR1.39 (PC8), JP5.3
unnamed: CR1.49 (PA14), SWD.1
unnamed: CR1.38 (PC7), JP5.5
unnamed: CR1.37 (PC6), JP5.7
unnamed: CR1.36 (PB15), JP5.9
unnamed: CR1.35 (PB14), JP5.11
unnamed: CR1.34 (PB13), JP5.13
unnamed: CR1.33 (PB12), JP5.15
unnamed: LED1.C, R4.1
unnamed: J1.1 (VUSB), JP1.2, R3.1
N_RST: C5.1, CR1.7 (NRST), SW1.2
OSC8_IN: C3.1, CR1.5 (PD0-OSC_IN), Q1.1
OSC8_OUT: CR1.6 (PD1-OSC_OUT), R2.2
OSC32_IN: C1.1, CR1.3 (PC14-OSC32_IN), LSO.2
OSC32_OUT: C2.1, CR1.4 (PC15-OSC32_OUT), LSO.1
USART1_RX: CR1.43 (PA10), S1.1
USART1_TX: CR1.42 (PA9), S1.2
USART2_RX: CR1.17 (PA3), S2.1
USART2_TX: CR1.16 (PA2), S2.2
USART3_RX: CR1.30 (PB11), S3.1
USART3_TX: CR1.29 (PB10), S3.2
VDD: 5V___3.3V.1, 5V___3.3V.2, C6.1, C7.1, C8.1, C9.1, C10.1, C11.1, C12.1, CR1.1 (VBAT), CR1.13 (VDDA), CR1.19 (VDD_4), CR1.32 (VDD_1), CR1.48 (VDD_2), CR1.64 (VDD_3), IC1.1 (VOUT), LED1.A


Board: 2 copper layers, 50.8 x 25.4 mm, 33 parts (1 on the bottom side), 34 nets.

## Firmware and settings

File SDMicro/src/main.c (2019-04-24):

/**
 *
 *
 *
 *
  ******************************************************************************
  * @file    main.c
  * @author  Luke Armbruster, Troy Conlin, and Keith Aylwin
  * @version V1.0
  * @date    11-January-2019
  * @brief   Main file for D2U microcontroller source.
  ******************************************************************************
*/

#include "stm32f0xx.h"
#include <stdio.h>
#include <stdlib.h>
#include <string.h>
#include "arm_math.h"
#include <math.h>
#include "stdbool.h"

#define IR_RECEIVE_MAX 1200
#define IR_NO_RECEIVE_MIN 2600
#define RX_BUFFER_MAX 100
#define TX_BUFFER_MAX 100
#define MC_ADDRESS 130

#define ARRAY_SIZE 8
#define RESOLUTION 8
#define LOOK_AHEAD    3.0f
//#define LOOK_AHEAD    1.732f
#define LOOK_AHEAD_SQ 9.0f
//#define LOOK_AHEAD_SQ 3.0f
#define NORMAL_SPEED 20
#define TIC_LENGTH 0.05461
#define VELOCITY_EQ_M 11.013
#define VELOCITY_EQ_B 20.0
//#define VELOCITY_EQ_B 9.5862
#define L_R_BIAS 1.23f   	//Multiply to Right Wheel
#define ACCEL 2
#define VEHICLE_WIDTH 0.6731
#define MAX_SPEED 30
#define MAX_MOTION_FAILURE_COUNT 30 //Each iteration is about a tenth of a second. So failure to move within 3 seconds

#define NORMAL_SPEED_3 40
#define TURN_COEFF 10
#define PI_VAR 3.14159

#define MAX_TURN 30 //20

#define AVERAGE_SPEED 0.1f //Average human walking speed is about 1.4 m/s // .15
#define ACCEL_2 4
#define DECEL_2 1
#define MAX_TORQUE 60

#define BREAK_DISTANCE 80

#define KPL 10.0f;
#define KPR 15.0f;

#ifndef _USE_PID_CONTROLLER
//#define _USE_PID_CONTROLLER
#endif

enum Encoders{RECEIVE, NO_RECEIVE};
enum Direction{FORWARD, REVERSE};
enum LastMotorSent{LEFT, RIGHT};
enum DisplayMode{START=0, ULTRASONICS=1, ENCODERS=2, DELIVERY=3, JETSON=4, END=5};
typedef struct {
	char address;
	char command;
	char data;
	char checksum;
} Packet;

typedef struct _Point {
	float x;
	float y;
} Point;


/* Display mode info */
static uint8_t current_mode = ULTRASONICS;

/* Encoder state vars */
enum Encoders prev_adc0_state = NO_RECEIVE; // Previous ADC channel 0 state
enum Encoders prev_adc1_state = NO_RECEIVE; // Previous ADC channel 1 state
enum Encoders adc0_state = NO_RECEIVE; // Current ADC channel 0 state
enum Encoders adc1_state = NO_RECEIVE; // Current ADC channel 1 state

enum Direction left_direction = FORWARD;
enum Direction right_direction = FORWARD;

static uint32_t adc0_val = 0; // Current ADC channel 0 reading
static uint32_t adc1_val = 0; // Current ADC channel 1 reading

static uint32_t adc_left_slots = 0; // Number of times a reading on ADC channel 0 has crossed the threshold - right
static uint32_t adc_right_slots = 0; // Number of times a reading on ADC channel 1 has crossed the threshold - left

static uint32_t adc_left_same_counter = 0;
static uint32_t adc_right_same_counter = 0;

static uint32_t last_used_adc_left_slots = 0; // Right
static uint32_t last_used_adc_right_slots = 0; // Left

static uint32_t last_encoder_left_count_to_jetson = 0;
static uint32_t last_encoder_right_count_to_jetson = 0;

static int16_t left_speed = NORMAL_SPEED; // Current left speed to be requested
static int16_t right_speed = NORMAL_SPEED; // Current right speed to be requested

/* UART vars */
static char last_message[RX_BUFFER_MAX]; // Contains last full string enclosed in curly braces

static char rx_buffer[RX_BUFFER_MAX]; // Buffer of received UART data
static uint16_t rx_buffer_index = 0;

static char jetson_tx_buffer[TX_BUFFER_MAX]; // Buffer of UART data to transmit
static uint16_t jetson_tx_buffer_index = 0;
static bool jetson_buffer_lock = false;

static char mc_tx_buffer[9]; // Buffer of UART data to transmit, place 255 in position 4 if only sending one packet
static uint8_t mc_tx_buffer_index = 0;

/* Ultrasonic vars */
static uint16_t elapsed_response_time = 0; // Response time since trigger was set high

static uint16_t us1_distance = 0; // Distance in centimeters of ultrasonic 1 to object
static uint8_t us1_started = 0;
static uint16_t us1_elapsed_echo_time = 0; // Elapsed ultrasonic echo time in us

static uint16_t us2_distance = 0; // Distance in centimeters of utlrasonic 2 to object
static uint8_t us2_started = 0;
static uint16_t us2_elapsed_echo_time = 0; // Elapsed ultrasonic echo time in us

static uint16_t us3_distance = 0; // Distance in centimeters of ultrasonic 3 to object
static uint8_t us3_started = 0;
static uint16_t us3_elapsed_echo_time = 0; // Elapsed ultrasonic echo time in us

static uint8_t disp_count = 0;

static uint16_t time_since_last_jetson_msg = 0; // Time in milliseconds since last message was received from jetson

static uint8_t delivery_requested = 1; // Indication that delivery was requested has been received from Jetson

/* Control Algorithm Variables */
static uint32_t encoder_diff_l = 0;
static uint32_t encoder_diff_r = 0;
static uint8_t  accel_count = 1;
static uint8_t  decel_count = 1;
static uint8_t  accel_fail_count = 0;
static uint8_t  decel_fail_count = 0;

static bool jetson_connected = false;
bool new_points_ready = false;
static uint16_t time_since_screen_change = 0;
float last_theta = 0;

int left_speed_integral[] = {0.0, 0.0, 0.0, 0.0, 0.0, 0.0, 0.0, 0.0, 0.0, 0.0};
int right_speed_integral[] = {0.0, 0.0, 0.0, 0.0, 0.0, 0.0, 0.0, 0.0, 0.0, 0.0};
//int integral_sum; // Positive on left wheel

float k_i = 0.0;
float k_p = 0.6;

/* New points from Jetson */
float new_points_x[] = {0.0, 0.0, 0.0, 0.0, 0.0, 0.0, 0.0, 0.0};
float new_points_y[] = {0.0, 0.0, 0.0, 0.0, 0.0, 0.0, 0.0, 0.0};

/* Current working points */
float orig_points_x[] = {0.0, 0.0, 0.0, 0.0, 0.0, 0.0, 0.0, -1.4};
float orig_points_y[] = {1.0,  2.0,  3.0,  4.0,  5.0, 6.0,  7.0,  8.4};

//float points_x[] = {0.0, 0.0, 0.0, 0.0, 0.0, 0.0, 0.0, 0.0};
//float points_y[] = {3.0,  6.0,  9.0,  12.0,  15.0, 18.0, 21.0, 24.0};

//float points_x[] = {-.95, -1.34, -1.73, -1.78, -2.56, -2.61, -3.0f, -3.39};
//float points_y[] = {18.33/5,  18.50/5,  18.67/5,  19.61/5,  19.95/5, 20.90/5, 21.07/5, 21.23/5};

//float points_x[] = {0.0, 0.0, 0.0, 0.0, 0.0, 0.0, 0.0, 0.0};
//float points_y[] = {0.0,  0.0,  0.0,  0.0,  0.0, 0.0,  0.0, 0.0};
float points_x[] = {0.4, 0.56, 0.86, 0.94, 1.06, 1.23, 1.33, 1.4};
float points_y[] = {0.6,  1.2,  1.8,  2.4, 3.0, 3.6,  4.2,  4.8};

float debug_goal_x[100];
int debug_goal_x_index = 0;
float goal_x = 0.0;
float goal_y = 0.0;

float prev_goal_x = 0.0;
float prev_goal_y = 0.0;
float heading = 0.0;

float pitch = 0.0;

uint8_t v_t = 0;
uint32_t zero_count = 0; //DIAGNOSTIC ONLY TODO REMOVE

/* Motor state vars */
Packet left_packet;
Packet right_packet;

/* Vars for debugging */
uint16_t num_chars_received = 0;
uint32_t loop_count = 0;

int int_count = 0;
int total_int_count = 0;

uint8_t motor_cmd_count = 0;

int8_t stall_count = 0;
float PI_dt = 0.0;
float wheelControl_dt = 0.0f;
bool brake = false;
bool e_stop = false;

static int int_counter = 0;

static void decodeJetsonString();

static void ADCInit();
static void USARTInit();
static void UltrasonicInit();
static void SPIInit();
static int Drive(enum Direction left_direction, int16_t left_speed, enum Direction right_direction, int16_t right_speed); // Return 1 if unable to send, 0 if commands sent
static void Cmd(char b);
static void Data(char b);
static void DispString(char* data);
static void SendEncoderCount();
static void nsWait(uint64_t t);

bool find_goal();
float distance_squared(float x1, float y1, float x2, float y2);
void SetMotors (uint32_t diff_l, uint32_t diff_r, float32_t diff_t);
void PointUpdate (uint32_t diff_l, uint32_t diff_r);
void wheelControl (uint32_t diff_l, uint32_t diff_r, float32_t diff_t);
void apply_brakes(uint32_t diff_l, uint32_t diff_r, float32_t diff_t);

int main(void) {
	ADCInit();
	USARTInit();
	SPIInit();
	UltrasonicInit();

	mc_tx_buffer[8] = 255; // Set end character in buffer

	/* Only one motor controller, so use this address */
	left_packet.address = MC_ADDRESS;
	right_packet.address = MC_ADDRESS;

	/* Send timeout packet */
	mc_tx_buffer[0] = MC_ADDRESS;
	mc_tx_buffer[1] = 14; // Serial timeout command
	mc_tx_buffer[2] = 10; // 1000ms timeout
	mc_tx_buffer[3] = (MC_ADDRESS + 10 + 14) & 127; // Checksum
	mc_tx_buffer[4] = 255; // Stop byte
	USART_ITConfig(USART2, USART_IT_TXE, ENABLE); // Send initial command to enable timeout
	nsWait(100000000);

	bool drive_enable = true;
	for(;;) {
		if(new_points_ready) {
			memcpy(points_x, new_points_x, sizeof(float) * 8);
			memcpy(points_y, new_points_y, sizeof(float) * 8);
			memset(new_points_x, 0.0f, sizeof(float) * 8);
			memset(new_points_y, 0.0f, sizeof(float) * 8);
			new_points_ready = false;
			last_theta = 0;
		}
		drive_enable = true;
		if(!delivery_requested) { // If the delivery has not been requested from the Jetson, don't drive
			drive_enable = false;
		}

		// Get encoder updates
		encoder_diff_l = adc_left_slots - last_used_adc_left_slots;
		last_used_adc_left_slots = adc_left_slots;
		encoder_diff_r = adc_right_slots - last_used_adc_right_slots;
		last_used_adc_right_slots = adc_right_slots;

		PointUpdate(encoder_diff_l, encoder_diff_r);

		if(drive_enable && !brake) {

			drive_enable = find_goal();

			if(drive_enable && !e_stop) {
				wheelControl(encoder_diff_l, encoder_diff_r, wheelControl_dt);
				wheelControl_dt = 0.0f;
			}
			nsWait(100000000);
		}
		else if(brake){
			apply_brakes(encoder_diff_l, encoder_diff_r, wheelControl_dt);
		}
		else {
			Drive(left_direction, 0, right_direction, 0);
		}

		/* Send over goal points to the Jetson */
		/*int32_t goal_x_int = goal_x * 100.0f;
		int32_t goal_y_int = goal_y * 100.0f;
		if(jetson_tx_buffer_index == 0) {
			jetson_tx_buffer[0] = '{';
			jetson_tx_buffer[1] = 'C';
			if(goal_x_int < 0) {
				jetson_tx_buffer[2] = '-';
				goal_x_int *= -1.0f;
			} else {
				jetson_tx_buffer[2] = '+';
			}
			for(int i = 0; i < 3; i++) {
				char digit = goal_x_int % 10 + '0';
				goal_x_int /= 10;
				jetson_tx_buffer[3 + i] = digit;
			}
			jetson_tx_buffer[6] = ',';
			if(goal_x_int < 0) {
				jetson_tx_buffer[7] = '-';
				goal_y_int *= -1.0f;
			} else {
				jetson_tx_buffer[7] = '+';
			}
			for(int i = 0; i < 3; i++) {
				char digit = goal_y_int % 10 + '0';
				goal_y_int /= 10;
				jetson_tx_buffer[8 + i] = digit;
			}
			jetson_tx_buffer[11] = '}';
			USART_ITConfig(USART1, USART_IT_TXE, ENABLE);
		}*/
	}
}


void PointUpdate (uint32_t diff_l, uint32_t diff_r) {
	float delta_theta = ((float)diff_r - (float)diff_l) * TIC_LENGTH / VEHICLE_WIDTH;
	if(delta_theta == 0.0f) {
		return;
	}
	float delta_x = -0.5 * TIC_LENGTH * ((float)diff_l + (float)diff_r) * sin(delta_theta);
	float delta_y = 0.5 * TIC_LENGTH * ((float)diff_l + (float)diff_r) * cos(delta_theta);

	float x_rot;
	float y_rot;

	for(int i = 0; i < ARRAY_SIZE; i++) {
		x_rot = (points_x[i] - delta_x) * cos(-delta_theta) + (points_y[i] - delta_y) * -sin(-delta_theta);
		y_rot = (points_x[i] - delta_x) * sin(-delta_theta) + (points_y[i] - delta_y) * cos(-delta_theta);

		points_x[i] = x_rot;
		points_y[i] = y_rot;
	}

	return;
}

/*
 * Send number of encoder ticks since last message was sent to Jetson
 */
static void SendEncoderCount() {
	uint32_t left_count_to_send = adc_left_slots - last_encoder_left_count_to_jetson;
	uint32_t right_count_to_send = adc_right_slots - last_encoder_right_count_to_jetson;
	/* If the encoder count deltas to the jetson are too high something is wrong - loop infinitely for now */
	last_encoder_left_count_to_jetson = adc_left_slots;
	last_encoder_right_count_to_jetson = adc_right_slots;
	char second_left_char = left_count_to_send % 10 + 48;
	left_count_to_send /= 10;
	char first_left_char = left_count_to_send % 10 + 48;

	char second_right_char = right_count_to_send % 10 + 48;
	right_count_to_send /= 10;
	char first_right_char = right_count_to_send % 10 + 48;

	int idx = 0;
	while(jetson_buffer_lock) { // Wait until buffer is available
		idx += 1;
	}

	jetson_buffer_lock = true;

	jetson_tx_buffer[0] = '{';
	jetson_tx_buffer[1] = 'E';
	jetson_tx_buffer[2] = first_left_char;
	jetson_tx_buffer[3] = second_left_char;
	jetson_tx_buffer[4] = ',';
	jetson_tx_buffer[5] = first_right_char;
	jetson_tx_buffer[6] = second_right_char;
	jetson_tx_buffer[7] = '}';
	jetson_tx_buffer[8] = '\0';
	USART_ITConfig(USART1, USART_IT_TXE, ENABLE);   // Enable USART1 Transmit interrupt
	int_counter++;
}

/*
 * Switch to next display mode
 */
static void nextMode() {
	current_mode = ULTRASONICS;
	/*if(current_mode >= END) {
		current_mode = START + 1;
	}*/
}

/*
 * Decode the remote controller message from the Jetson and set desired wheel speed.
 */
/*static void decodeControllerMsg() {
	time_since_last_jetson_msg = 0;
	left_speed = (last_message[5] - 48) + (last_message[4] - 48) * 10 + (last_message[3] - 48) * 100;
	right_speed = (last_message[10] - 48) + (last_message[9] - 48) * 10 + (last_message[8] - 48) * 100;
	if(last_message[2] == '+') {
		left_direction = FORWARD;
	} else if(last_message[2] == '-') {
		left_direction = REVERSE;
	}
	if(last_message[7] == '+') {
		right_direction = FORWARD;
	} else if(last_message[7] == '-') {
		right_direction = REVERSE;
	}
}*/

/*
 *  Decodes the points message sent from the Jetson
 */
static void decodePointUpdateMsg() {
	const char comma[2] = ",";
	// Ignoring { and K
	char* token = strtok(last_message, comma);

	for(int i = 0; i < 8; i++) {
		token = strtok(NULL, comma);
		new_points_x[i] = atof(token);
		token = strtok(NULL, comma);
		new_points_y[i] = atof(token);
	}
	token = strtok(NULL, comma);
	pitch = atof(token);
	new_points_ready = true;
}

/*
 * Determine which type of message was received from the Jetson and parse the data accordingly.
 */
static void decodeJetsonString() {
	switch (last_message[1]) {
	case 'A': // Arbitrate new points coming in
		// TODO: Apply braking arbitration
		break;

	case 'K': // Points for control algorithm
		decodePointUpdateMsg();
		break;
	case 'C': // Remote controller feedback
		//decodeControllerMsg();
		break;
	case 'M': // Mode swtich
		nextMode();
		break;
	case 'N': // Cancel delivery request
		delivery_requested = 0;
		break;
	case 'D': // Delivery request received
		// Reassign points for continuous testing
		/*for(unsigned int i = 0; i < 8; i++) {
			points_x[i] = orig_points_x[i];
			points_y[i] = orig_points_y[i];
		}*/
		delivery_requested = 1;
		break;
	case 'S': // Switch modes for controller requested
		/*if(current_mode == CHANGE_MODE) {
			use_ps4_controller = !use_ps4_controller;
			left_speed = 0;
			right_speed = 0;
		}*/
		break;
	default:
		break;
	}
}


/*************************************************************************
*	Function to send commands to the motor controllers
*
*	Returns 1 if still sending the previous command, 0 otherwise.
*
**************************************************************************/
static int Drive(enum Direction left_direction_v, int16_t left_speed_v, enum Direction right_direction_v, int16_t right_speed_v) {
	if(mc_tx_buffer_index != 0) {
		return 1; // Haven't finished sending the last message
	}
	if(left_speed_v < 0) {
		left_speed_v = -1 * left_speed_v;
		left_direction_v = REVERSE;
	} else if(left_speed_v > 80) {
		left_speed_v = 80;
	}
	if(right_speed_v < 0) {
		right_speed_v = -1 * right_speed_v;
		right_direction_v = REVERSE;
	} else if(right_speed_v > 80) {
		right_speed_v = 80;
	}


	//DIAGNOSTIC ONLY ZERO COUNT TODO REMOVE
	if(left_speed_v == 0 || right_speed_v == 0) {
		zero_count++;
	}

	if(left_direction_v == FORWARD) {
		left_packet.command = 4;
	}
	else if(left_direction_v == REVERSE) {
		left_packet.command = 5;
	}
	if(right_direction_v == FORWARD) {
		right_packet.command = 0;
	}
	else if(right_direction_v == REVERSE) {
		right_packet.command = 1;
	}
	left_packet.data = left_speed_v;
	right_packet.data = right_speed_v;

	left_packet.checksum = (left_packet.address + left_packet.command + left_packet.data) & 127;
	right_packet.checksum = (right_packet.address + right_packet.command + right_packet.data) & 127;

	mc_tx_buffer[0] = left_packet.address;
	mc_tx_buffer[1] = left_packet.command;
	mc_tx_buffer[2] = left_packet.data;
	mc_tx_buffer[3] = left_packet.checksum;

	mc_tx_buffer[4] = right_packet.address;
	mc_tx_buffer[5] = right_packet.command;
	mc_tx_buffer[6] = right_packet.data;
	mc_tx_buffer[7] = right_packet.checksum;
	USART_ITConfig(USART2, USART_IT_TXE, ENABLE);

	return 0;
}


/*************************************************************************
*	IR Encoder Interrupt
*
*	Increments counter indicating that the IR receiver transitioned between receiving a reflection and not and vice versa. Multiply adcx_slots by resolution to get distance traveled.
*
**************************************************************************/
void TIM2_IRQHandler() {
	PI_dt += 0.006;
	wheelControl_dt += 0.006;
	TIM2->SR &= 0x00;	// Clear the IRQ flag

	ADC1->CHSELR = 0;                 		// Deselect ADC Channels
	ADC1->CHSELR |= 1 << 8;           		// Select Channel 8 (PB0)
	while(!(ADC1->ISR & ADC_ISR_ADRDY)); 	// Wait for ADC to be ready
	ADC1->CR |= ADC_CR_ADSTART;       		// Start the ADC
	while(!(ADC1->ISR & ADC_ISR_EOC));		// Wait for end of conversion
	adc0_val = ADC1->DR;					// Store value in file var

    ADC1->CHSELR = 0;                 		// Deselect ADC Channels
    ADC1->CHSELR |= 1 << 9;           		// Select Channel 9 (PB1)
	while(!(ADC1->ISR & ADC_ISR_ADRDY));  	// Wait for ADC to be ready
	ADC1->CR |= ADC_CR_ADSTART;       		// Start the ADC
	while(!(ADC1->ISR & ADC_ISR_EOC));		// Wait for end of conversion
	adc1_val = ADC1->DR;					// Store value in file var


	// Update slot counters
	if(adc0_val > IR_NO_RECEIVE_MIN) {
		adc0_state = NO_RECEIVE;
	} else if(adc0_val < IR_RECEIVE_MAX) {
		adc0_state = RECEIVE;
	} else {
		adc0_state = prev_adc0_state;
	}
	if(adc1_val > IR_NO_RECEIVE_MIN) {
		adc1_state = NO_RECEIVE;
	} else if(adc1_val < IR_RECEIVE_MAX) {
		adc1_state = RECEIVE;
	} else {
		adc1_state = prev_adc1_state;
	}

	if(adc0_state != prev_adc0_state) {
		if(adc_left_same_counter > 1) {
			adc_left_slots++;
		}
		prev_adc0_state = adc0_state;
		adc_left_same_counter = 0;
	} else {
		adc_left_same_counter++;
	}
	if(adc1_state != prev_adc1_state) {
		if(adc_right_same_counter > 1) {
			adc_right_slots++;
		}
		prev_adc1_state = adc1_state;
		adc_right_same_counter = 0;
	} else {
		adc_right_same_counter++;
	}
}


/*************************************************************************
*	UART TX/RX Interrupt
*
*	Received UART data goes into the rx_buffer
*	To transmit UART data, set jetson_tx_buffer_index to 0, copy the data to send into the jetson_tx_buffer, and enable TXE interrupts.
*
**************************************************************************/
void USART1_IRQHandler() {
	if(USART1->ISR & USART_ISR_ORE) { // Overran buffer
		USART1->ICR |= USART_ICR_ORECF;
		memset(rx_buffer, '\0', RX_BUFFER_MAX);
		rx_buffer_index = 0; // Reset buffer index
	}
	if((USART1->ISR & USART_ISR_RXNE) == USART_ISR_RXNE) { // Check if RXNE flag is set
		if(rx_buffer_index < RX_BUFFER_MAX) {
			char in_char = (uint8_t) USART1->RDR;
			num_chars_received++;
			if(rx_buffer_index == 0 && in_char != '{') {
				return; // Ignoring data that is not contained within braces
			}
			rx_buffer[rx_buffer_index++] = in_char;
			if(in_char == '}') {
				jetson_connected = true;
				memcpy(last_message, rx_buffer, rx_buffer_index * sizeof(char)); // Copy completed message to memory
				memset(rx_buffer, '\0', RX_BUFFER_MAX); // Clear buffer
				decodeJetsonString();
				rx_buffer_index = 0; // Reset buffer index
			}
		} else {
			// Error. Overran buffer without terminating JSON message.
			memset(rx_buffer, '\0', RX_BUFFER_MAX); // Clear buffer
			rx_buffer_index = 0; // Reset buffer index
		}
	}
	if((USART1->ISR & USART_ISR_TC) == USART_ISR_TC) { // Check if TXE flag is set
		if(jetson_tx_buffer[jetson_tx_buffer_index] != '\0') {
			USART1->TDR = jetson_tx_buffer[jetson_tx_buffer_index++]; // Load next character into data register
		} else {
			USART_ITConfig(USART1, USART_IT_TXE, DISABLE);
			memset(jetson_tx_buffer, '\0', TX_BUFFER_MAX);
			jetson_tx_buffer_index = 0;
			jetson_buffer_lock = false;
		}
	}
}


/*************************************************************************
*	UART TX Interrupt
*
*	To transmit UART data, set mc_tx_buffer_index to 0, copy the data to send into the mc_tx_buffer, and enable TXE interrupts.
*
**************************************************************************/
void USART2_IRQHandler() {
	if(USART2->ISR & USART_ISR_TXE) { // Check if TXE flag is set
		if(mc_tx_buffer[mc_tx_buffer_index] != 255) {
			USART2->TDR = mc_tx_buffer[mc_tx_buffer_index++]; // Load next character into data register
		} else {
			USART_ITConfig(USART2, USART_IT_TXE, DISABLE);
			memset(mc_tx_buffer, 255, 9);
			mc_tx_buffer_index = 0;
		}

	}
}
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

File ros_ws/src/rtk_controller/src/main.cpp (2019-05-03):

/*
* @brief This program handles broadcasting points to the microcontroller in its current reference frame. It takes into account the current position and 
*           heading of the robot as reported by the EKF and plans a trajectory to the next waypoint. #ifdef guards are used when wanting to use a different algorithm to calculate the points.
*           A* algorithm is self contained in this package.
* @author Luke Armbruster
* @bug Point projection onto the waypoint line itself instead of a trajectory between the robot and the next waypoint has not been confirmed to work. Boost precision library had to be used since a double did not have enough precision for the calculation (may take a performance hit).
*/
#include <chrono>
#include <exception>
#include <iomanip>
#include <map>
#include <sstream>
#include <thread>

/* OpenCV */
#include <image_transport/image_transport.h>
#include <cv_bridge/cv_bridge.h>

#include "std_msgs/String.h"
#include "std_msgs/Float32.h"
#include "sensor_msgs/NavSatFix.h"
#include "sensor_msgs/Imu.h"
#include "ros/callback_queue.h"
#include "ros/ros.h"
#include "../include/MapNode.h"
#include "../include/MapData.h"
#include "../include/xml_reader.h"
#include "rtk/HeadingSpeed.h"

/* Local Navigation Includes */
#include "../include/Map.h"
#include "../include/Node.h"
#include "../include/LocalOp.h"

/* OpenGL */
#include "../include/GLDebug.h"
#include "GL/freeglut.h"
#include "GL/gl.h"

#include <boost/math/constants/constants.hpp>
#include <boost/multiprecision/cpp_dec_float.hpp>
#include <limits>

#define ACCEPTED_DISTANCE_TO_WAYPOINT 10.0f
#define SERIES_LENGTH 8

#ifndef _USE_OBSTACLE_MAP
//#define _USE_OBSTACLE_MAP 
#endif

#ifndef _USE_A_STAR_INTERPOLATION
//#define _USE_A_STAR_INTERPOLATION 
#endif

#ifndef _USE_STRAIGHT_LINE
#define _USE_STRAIGHT_LINE
#endif

#ifndef _USE_OPEN_GL
//#define _USE_OPEN_GL
#endif


static const float pi = 3.1415927;
static ros::Publisher cmd_pub;
static ros::Publisher wpt_pub;
static ros::Publisher goal_pub;
static ros::Publisher goal_math_pub;
static enum MapData::positionStatus position_status = MapData::FixNotValid;
static double cur_heading_gps;
static double cur_speed;
static std_msgs::String pub_msg;
static sensor_msgs::NavSatFix wpt_msg;
static std_msgs::Float32 pitch_msg;
static sensor_msgs::NavSatFix goal_msg;
static sensor_msgs::NavSatFix goal_math_msg;

static std::chrono::time_point<std::chrono::system_clock> last_ekf_received_time = std::chrono::system_clock::now(); // Last time a message was received from the EKF
static std::chrono::time_point<std::chrono::system_clock> time_last_position_series_sent = std::chrono::system_clock::now(); // Time that the last string of points was sent to the micro
//static std::chrono::duration<double> time_since_last_position_series_sent;

static std::string next_waypoint_key = "";
static std::string prev_waypoint_key = "";
static MapNode prev_waypoint = MapNode(0.0f, 0.0f);
static float cur_heading_ekf = 0.0f; // Most recent heading received from the EKF

static float x_series[SERIES_LENGTH] = {0.0f, 0.0f, 0.0f, 0.0f, 0.0f, 0.0f, 0.0f, 0.0f};
static float y_series[SERIES_LENGTH] = {0.0f, 0.0f, 0.0f, 0.0f, 0.0f, 0.0f, 0.0f, 0.0f};

static float lat_series[SERIES_LENGTH] = {0.0f, 0.0f, 0.0f, 0.0f, 0.0f, 0.0f, 0.0f, 0.0f};
static float lon_series[SERIES_LENGTH] = {0.0f, 0.0f, 0.0f, 0.0f, 0.0f, 0.0f, 0.0f, 0.0f};


static std::pair<double, double> cur_coord(41.0f, -86.0f);

static sensor_msgs::ImageConstPtr img_msg;
static float pitch = 0.0f;

/*
*  Convert the floating point series to strings to publish to micro
*/
void convertPubMsg() {
    pub_msg.data = "{K";
    for(int i = 0; i < SERIES_LENGTH; i++) {
        std::stringstream x_stream;
        std::stringstream y_stream;
        x_stream << std::fixed << std::setprecision(2) << x_series[i];
        y_stream << std::fixed << std::setprecision(2) << y_series[i];
        pub_msg.data += ",";
        pub_msg.data += x_stream.str();
        pub_msg.data += ",";
        pub_msg.data += y_stream.str();
    }
    std::stringstream pitch_stream;
    pitch_stream << std::fixed << std::setprecision(3) << pitch;
    pub_msg.data += ",";
    pub_msg.data += pitch_stream.str();
    pub_msg.data += "}";
}

/*
* Take in the lidar map and update stored image
*/
void LocalMapCallback(const sensor_msgs::ImageConstPtr& msg) {
    try {
        img_msg = msg;
    } catch(cv_bridge::Exception& e) {
        ROS_ERROR("Could not convert from '%s' to 'bgr8'.", msg->encoding.c_str());
    }
}

/*
*  Store the most recent heading from the EKF until a filtered NavSatFix message is received
*/
void EKFHeadingCallback(const sensor_msgs::Imu::ConstPtr& msg) { 
    cur_heading_ekf = 2 * pi - msg->orientation.y; // Rotation is inverted from standard notation
}

void PitchCallback(const std_msgs::Float32::ConstPtr& msg) {
    pitch = msg->data ;
}
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

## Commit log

2016-02-11 Fixing serial transmission to micro
    [serial_manager.py]
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2018-04-02 Fixed timer continuing when going back from second controller to first
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2018-12-31 Created initial board schematic
    [PrototypeMcu.sch, untitled.sch]
2018-12-31 All wires traced but ground plane is not complete
    [PrototypeMcu.brd, PrototypeMcu.sch]
2018-12-31 Design rules check out
    [PrototypeMcu.brd]
2018-12-31 DRC changes
    [PrototypeMcu.brd]
2018-12-31 Added a fuse and impedance matched clock signals
    [PrototypeMcu.brd, PrototypeMcu.sch]
2018-12-31 LED and silkscreen Aded
    [PrototypeMcu.brd, PrototypeMcu.sch]
2019-01-01 Order placed to OSH Park
    [PrototypeMcu.brd]
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2019-01-05 Updating naming convention of pub/sub to match readme. BUG: Noticed bug where an invalid GPGGA message is being passed when the GPS first has power applied to it. Double check the string comparison f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
    [ntripclient.cpp]
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2019-01-09 Optical Encoer Diagram
    [IREncoder.brd, IREncoder.sch]
2019-01-10 Optical Encoder PCB updates. Awaits peer review and shipment
    [IREncoder.brd]
2019-01-16 Fixed issue in ntrip client where caster disconnects and doesn't recover. Added controller package to handle basic navigation
    [ntripclient.cpp]
2019-01-21 Removing unnecessary joystick driver causing problems on lubuntu for rPi
2019-01-24 Adding micro project to repo
    [SDMicro Run.cfg]
2019-01-24 Fixing rc_manager and pushing latest iOS code
    [SDMicro Debug.cfg, SDMicro Run.cfg]
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2019-01-27 Adding proper interrupts for UART tx/rx
    [SDMicro Run.cfg]
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2019-02-06 Library with IMU parts footprint
    [Adafruit BNO055.brd, Adafruit BNO055.sch]
2019-02-06 Adding USB to UART schematic and library
    [CP2102 breakout.brd, CP2102 breakout.sch]
2019-02-07 Lib and schematics for NS-HP-GL breakout board footprint
    [Board.brd, Board.sch]
2019-02-07 Adding PCB with UART converter components
    [Main.brd, Main.sch]
2019-02-07 Adding better UART breakout board
    [FT232R-Breakout_v37.brd, FT232R-Breakout_v37.sch]
2019-02-07 Adding miniusb UART converter and updating main to include IMU
    [FT232R-Breakout_v37.brd, FT232R-Breakout_v37.sch, Main.brd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]
2019-02-07 Fixing NS-HP-GL library and importing footprint to main PCB
    [Main.brd, Main.sch]
2019-02-07 Cleaning up PCB folders aand updating proper dimensioned GPS chip
    [Main.brd, Main.sch]
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2019-02-08 Updating boaard file and removing settings from git
    [Main.brd, Main.sch]
2019-02-08 Updating current board for review
    [Main.brd]
2019-02-08 Fixing mirrored FTDI on reverse of board
    [Main.brd]
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2019-02-15 Adding microcontroller to project
    [Main.brd, Main.sch]
2019-02-15 Connected JSTs and arranged them in schematic
    [Main.brd, Main.sch]
2019-02-16 First major layout session. Fixed up wanrings in GPS_UART module in the sensor module, and in the microcontroller module
    [Main.brd, Main.sch]
2019-02-16 Continued finishing the Schematic for the board
    [Main.brd, Main.sch]
2019-02-16 Cleaning up UART converter schematic
    [Main.brd, Main.sch]
2019-02-16 Fixing UART converter
    [Main.brd, Main.sch]
2019-02-16 Initial layout of main components
    [Main.brd, Main.sch]
2019-02-17 Cleaning up layout on main PCB
    [Main.brd, Main.sch]
2019-02-17 Further improvements on main PCB
    [Main.brd]
2019-02-17 Started routing
    [Main.brd]
2019-02-17 Routed power, routed encoders, routed ultrasonics, and logic level converters
    [Main.brd, Main.sch]
2019-02-18 Completed routing and awaiting review
    [Main.brd, Main.sch]
2019-02-18 Made improvements to routing, labelling, and added test vias
    [Main.brd, Main.sch]
2019-02-18 Cleaned up ground trace
    [Main.brd]
2019-02-18 Fixed board to adhere to DRC's and fixed schematic to adhere to ERC's
    [Main.brd, Main.sch]
2019-02-18 Increasing +3V3 width to micro
    [Main.brd]
2019-02-18 Fixed labelling sizes and locations
    [Main.brd]
2019-02-19 Moved two vias
    [Main.brd]
2019-02-19 Routed decoupling caps closer to micro and added vias for extra GPIO
    [Main.brd, Main.sch]
2019-02-19 Minor routing improvements
    [Main.brd]
2019-02-20 Adding CAAM outputs
    [copper_bottom.gbr, copper_top.gbr, drills.xln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]
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2019-02-20 Fixing ground trace under antenna
    [Main.brd]
2019-02-20 Fixing board routing and adding reset pin per Todd's suggestions
    [Main.brd, Main.sch]
2019-02-20 Routed headers for IMU backup
    [Main.brd, Main.sch]
2019-02-21 Fixing IMU traces and adding descriptive net names
    [Main.brd, Main.sch]
2019-02-21 Fixed minor routing problems
    [Main.brd]
2019-02-21 More routing and naming improvements
    [Main.brd, Main.sch]
2019-02-21 Minor routing improvements and net naming
    [Main.brd, Main.sch]
2019-02-21 More improvements on trace widths, orientations
    [Main.brd]
2019-02-22 More minor trace improvements
    [Main.brd]
2019-02-22 Minor routing fixes
    [Main.brd]
2019-02-22 Added pullup resistors for SDA and SCL
    [Main.brd, Main.sch]
2019-02-22 Updating encoder board to fix clearance issues and voltage level
    [IREncoder.brd, IREncoder.sch]
2019-02-23 Added indicator LEDs to board and cleaned up iOS assets
    [Main.brd, Main.sch]
2019-02-23 Cleaning up routing and labels for design review
    [IREncoder.brd, Main.brd, Main.sch]
2019-02-24 Added a resettable fuse to the boards
    [Main.brd, Main.sch]
2019-02-24 Added text to the PTC reset fuse
    [Main.brd]
2019-02-25 Moving labels to correct layer for silkscreen and added a view more descriptive labels
    [Main.brd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]
2019-02-25 Added ground planes to top and bottom for ordering
    [Main.brd]
2019-02-25 Updating board number and silkscreen layers for second order
    [Main.brd]
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2019-02-27 Adding diode for lidar protection
    [Main.brd, Main.sch]
2019-02-27 More trace cleanup
    [Main.brd]
2019-02-27 Fixing ground trace width
    [Main.brd]
2019-02-27 Minor trace fix
    [Main.brd]
2019-02-27 Fixing trace widths and net names
    [Main.brd, Main.sch]
2019-02-27 Fixing trace angle to ADC power
    [Main.brd]
2019-02-27 AAdding decoupling capacitors for design review
    [Main.brd, Main.sch]
2019-02-28 Adding lidar to regulated 5V on board
    [Main.brd, Main.sch]
2019-02-28 Fixed motor controller circuit
    [Main.brd, Main.sch]
2019-02-28 Fixing trace width on sabertooth ground
    [Main.brd]
2019-02-28 Fixed GPIO headers, USB pull downs, caps at input and output of regulator
    [Main.brd, Main.sch]
2019-02-28 Increased trace width and added backup switching regulator support circuitry
    [Main.brd, Main.sch]
2019-03-01 Fixing GPIO pin bank
    [Main.brd, Main.sch]
2019-03-01 More luke changes
    [Main.brd]
2019-03-01 Alright re routed nRST, Destroyed the ultrasonic routing
    [Main.brd, Main.sch]
2019-03-02 Finished moving encoders and reset pin
    [Main.brd, Main.sch]
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2019-03-02 Fixing logic converter circuit
    [Main.brd, Main.sch]
2019-03-02 Adding decoupling cap at 3V into logic converter
    [Main.brd, Main.sch]
2019-03-03 Connecting 5V line for display IC
    [Main.brd]
2019-03-04 Moving some traces for final design
    [Main.brd]
2019-03-04 Added a TL431 and Thyristor
    [Main.brd, Main.sch]
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2019-03-05 Minor trace routing changes
    [Main.brd]
2019-03-05 Moving a couple traces close to pads
    [Main.brd]
2019-03-05 Added some mounting holes
    [Main.brd]
2019-03-05 Updating with latest PCB submission
    [Main.brd, Main.sch, PCBDebug.cfg]
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2019-03-29 Fixing UART communication logic
    [main.c]
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2019-03-31 Some fixes to USART comms to Jetson
    [main.c]
2019-04-01 Fixing serial timeout and adding firebase module to launch file
    [serial_manager.py]
2019-04-01 Fixing main to reduce ultrasonic polling cost and increasing baud rate between Jetson and micro
    [main.c]
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2019-04-06 Fixing divide by zero error if x point doesn't change
    [main.c]
2019-04-07 More fixes to control algorithm
    [main.c]
2019-04-07 More control algorithm fixes
    [main.c]
2019-04-11 Fixing initial EKF heading and broadcasting points for control algorithm
    [main.cpp]
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2019-04-13 Updating control algorithm to improve performance on grades
    [SDMicro Debug.cfg]
2019-04-14 Fixing issues with object avoidance map
    [main.cpp]
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2019-04-15 Minor fixes to obstacle avoidance code
    [main.cpp]
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2019-04-16 Fixed a slope calculation and removed some hairy logic
    [main.c]
2019-04-17 Broken calculations for waypoint navigation
    [main.cpp]
2019-04-17 More broken code veyh tired asend help
    [main.cpp]
2019-04-17 Updating with mikes fixes
    [main.cpp]
2019-04-18 Potentially fixing issue with no RTK corrections
    [ntripclient.cpp]
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2019-04-23 Some changes were made to the control algo
    [SDMicro Run.cfg]
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

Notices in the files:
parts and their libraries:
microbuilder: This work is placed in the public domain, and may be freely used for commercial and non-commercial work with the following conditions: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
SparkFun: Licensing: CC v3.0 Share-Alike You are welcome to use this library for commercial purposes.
